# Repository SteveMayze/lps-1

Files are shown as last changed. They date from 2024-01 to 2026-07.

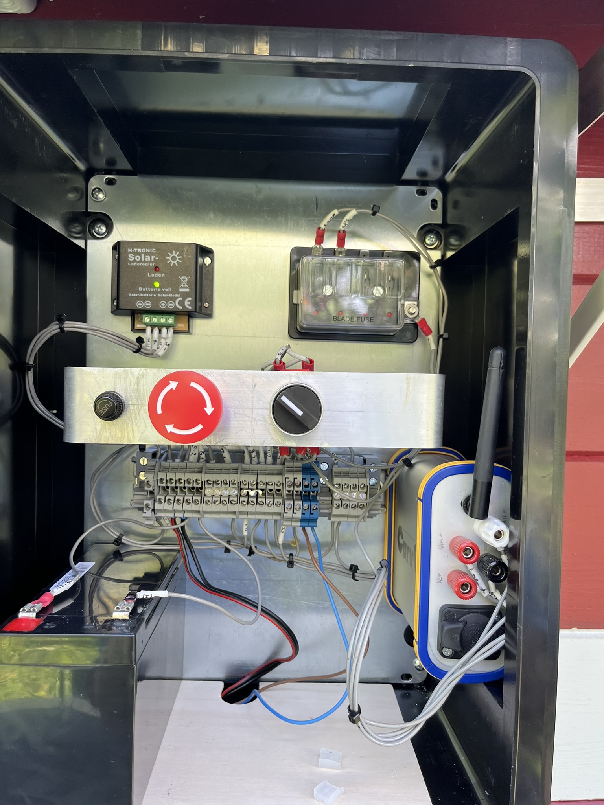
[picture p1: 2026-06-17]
Wiring/LPS-1 Wiring/doc/IMG_8326.JPEG

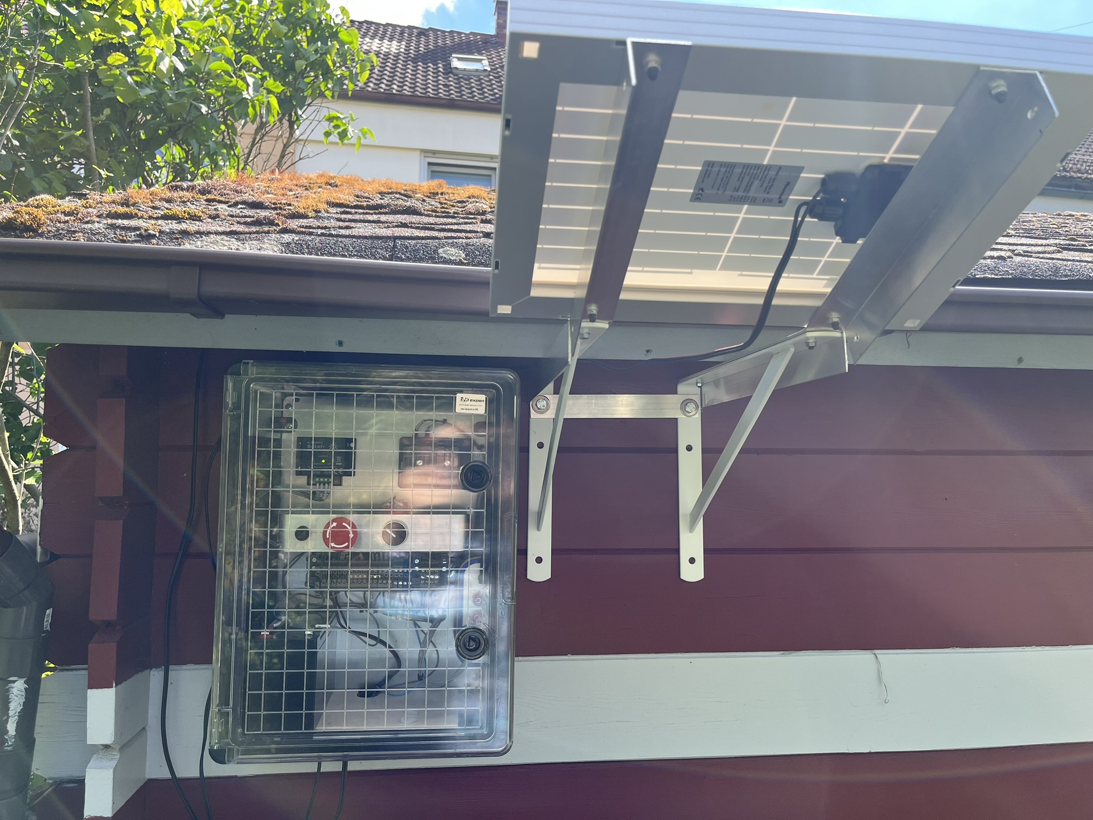
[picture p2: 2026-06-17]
Wiring/LPS-1 Wiring/doc/IMG_8325.JPEG

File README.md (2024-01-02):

# Solar Power Sensor LPS-1

A simple remote sensing node to monitor the voltage and load current for a solar/battery unit.
This unit brings together the prototype projects [Gateway Node](https://github.com/SteveMayze/leawood_gateway),  [Atmega1608 Development board](https://github.com/SteveMayze/atmega1608_dev) and [Sensor node firmware (Atmega1608 and INA219)](https://github.com/SteveMayze/PowerSensor-Atmega1608) to create a unified PCB that can be deployed to the field to make a connection to the gateway project in order to transfer the sensor data to the internet.

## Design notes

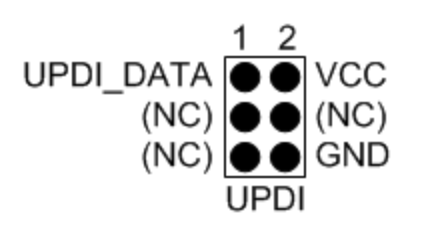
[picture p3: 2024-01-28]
doc/UPDI_PINOUT.png

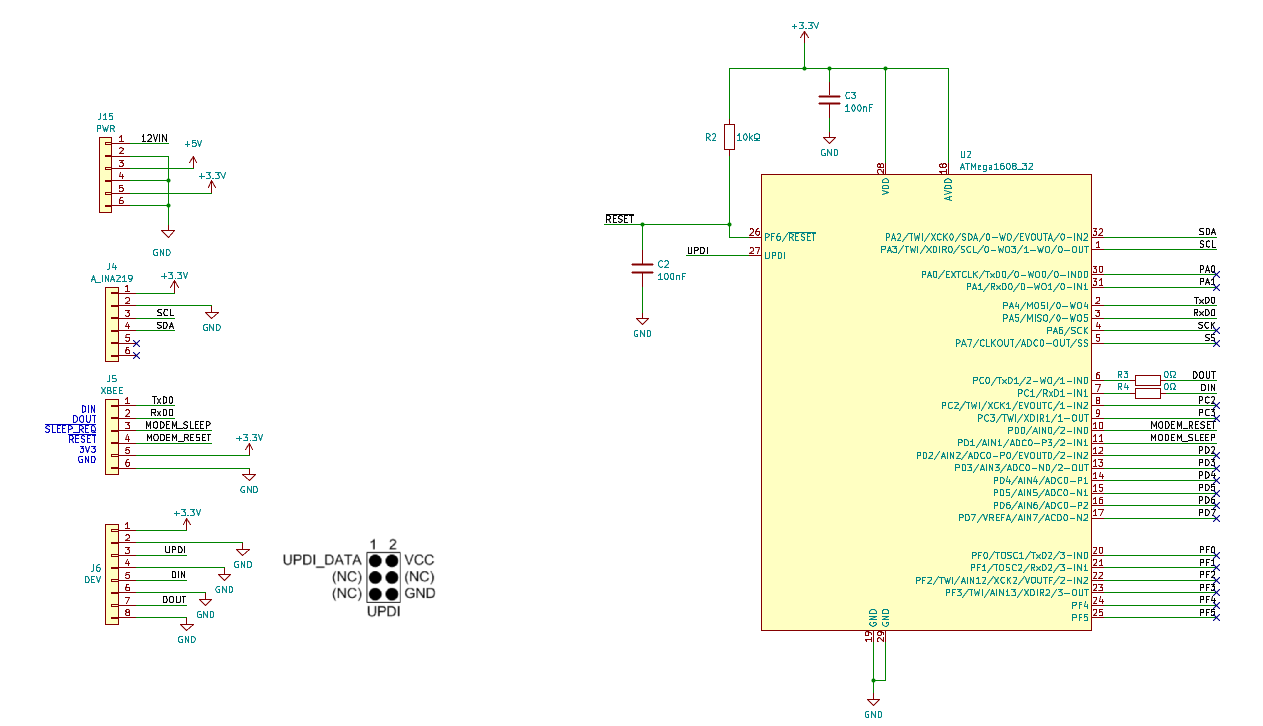
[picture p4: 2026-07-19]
doc/Schematic.png

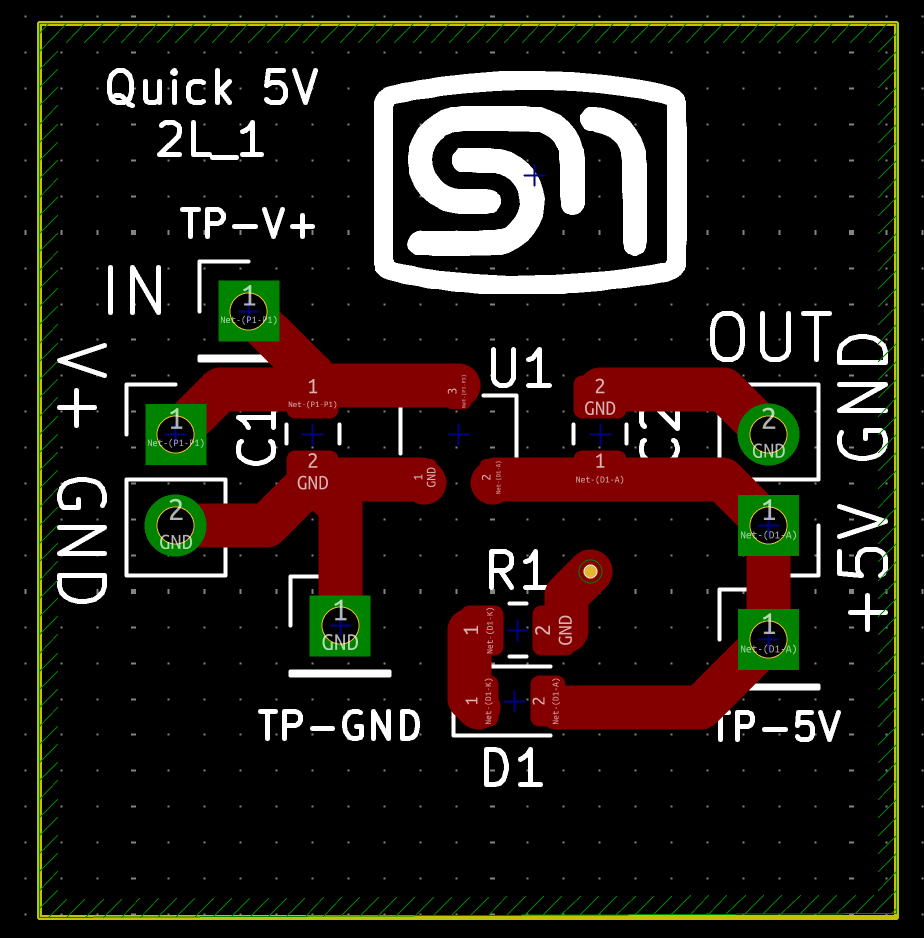
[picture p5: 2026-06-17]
doc/KiCad-PCB-Sample.png

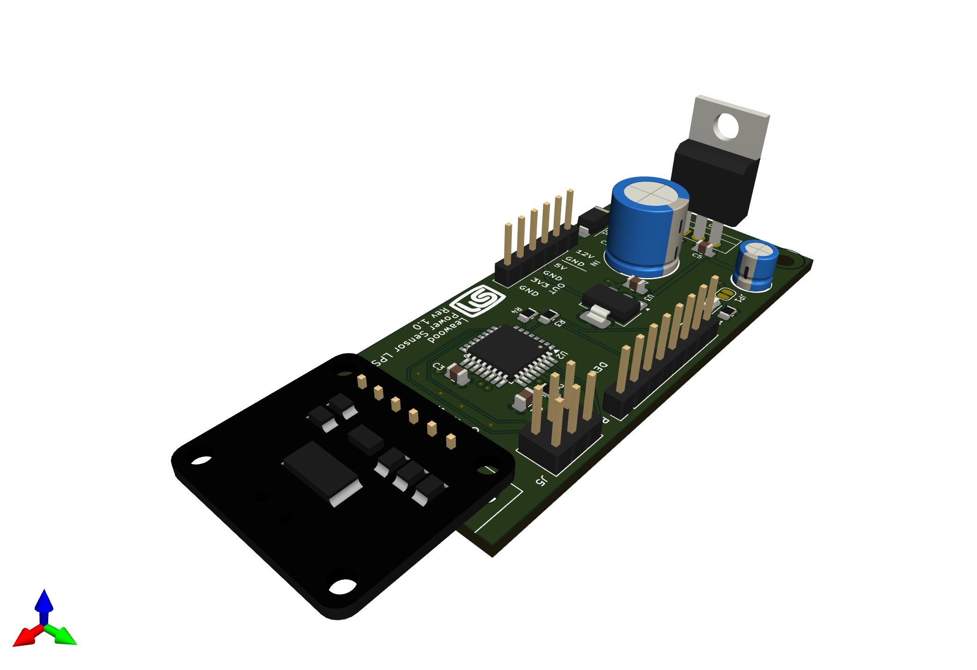
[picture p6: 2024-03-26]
doc/lps-1.jpg

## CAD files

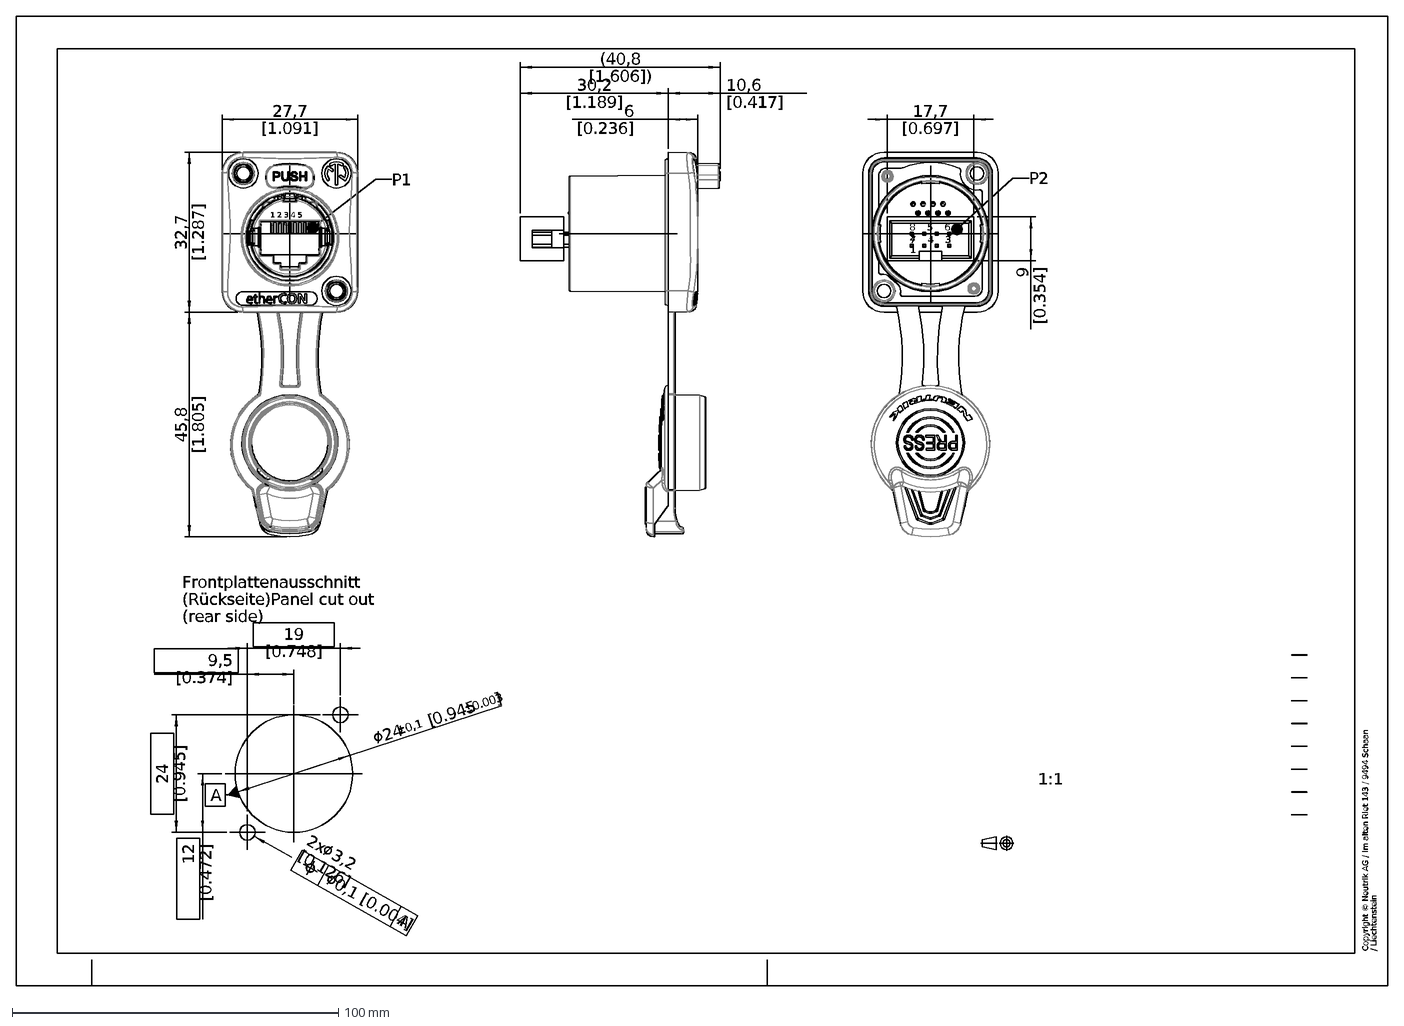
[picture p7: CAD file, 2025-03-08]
doc/Drawing NE8FDIS-TOP.dxf
Copyright © Neutrik AG / Im alten Riet 143 / 9494 Schaan / Liechtenstein
27,7 [1.091]
32,7 [1.287]
45,8 [1.805]
30,2 [1.189]
(40,8 [1.606])
10,6 [0.417]
6 [0.236]
17,7 [0.697]
9 [0.354]
24
0,1
[
0.945
0.003
]
2x 3,2 [0.126]
19 [0.748]
24 [0.945]
9,5 [0.374]
12 [0.472]
0,1 [0.004]
A
7 4 3 1
8 5 6 2
1 2 3 4 5 6 7 8
Frontplattenausschnitt (Rückseite) Panel cut out (rear side)
P1
P2
1:1

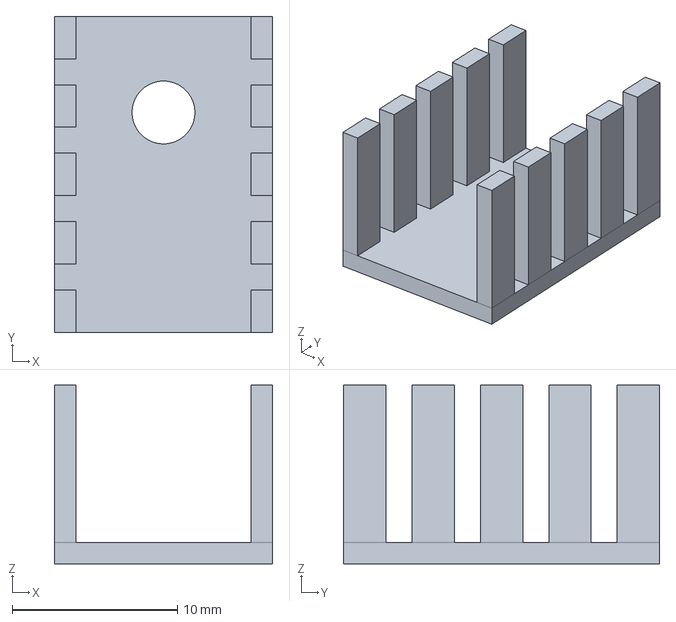
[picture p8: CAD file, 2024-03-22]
models/Wakefield-E274.step
13.2 x 19.1 x 10.8 mm

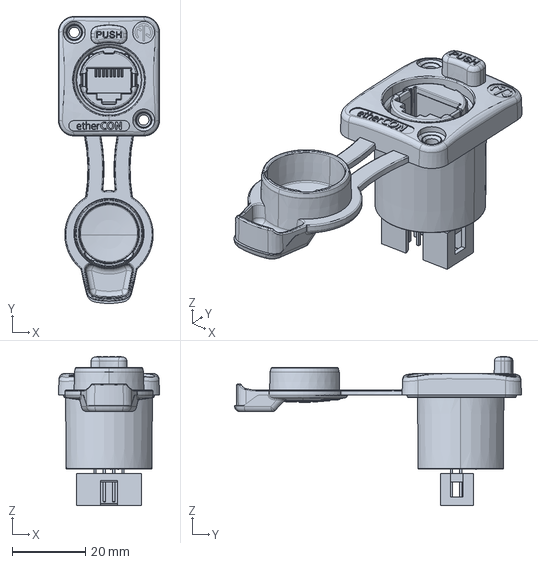
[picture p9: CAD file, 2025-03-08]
doc/3D File NE8FDIS-TOP.stp
27.7 x 78.6 x 40.8 mm

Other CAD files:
doc/ConnectorPanel.FCStd
models/Wakefield-E274-Body.step
models/Wakefield-E274.FCStd

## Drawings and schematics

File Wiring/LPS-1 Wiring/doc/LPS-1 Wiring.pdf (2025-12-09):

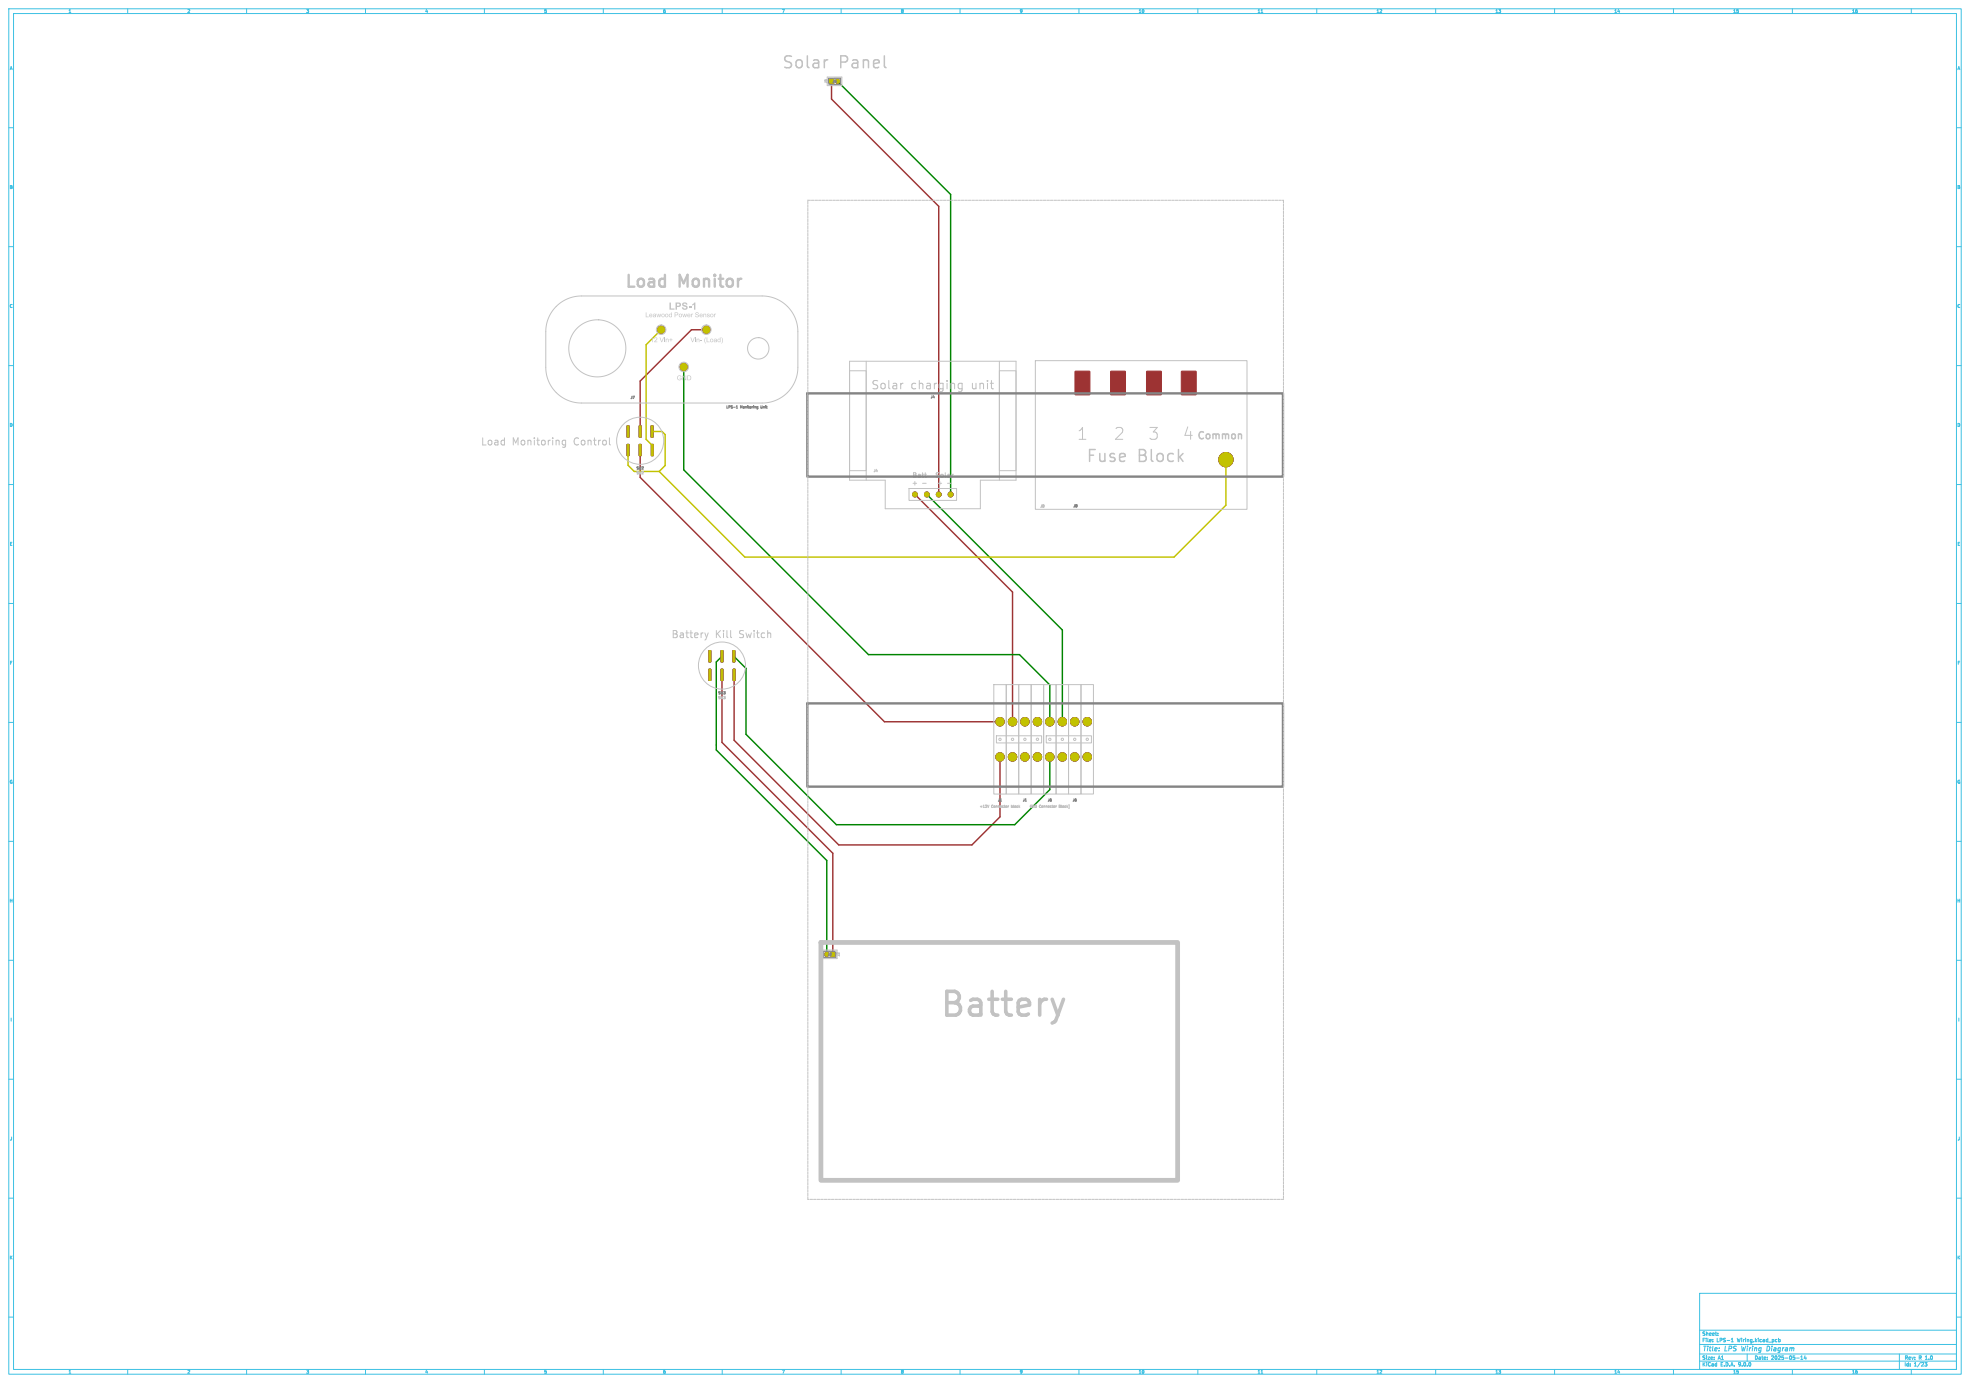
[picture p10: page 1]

J4 Solar charging | unit

Id: 1/23 Title: LPS Wiring Diagram

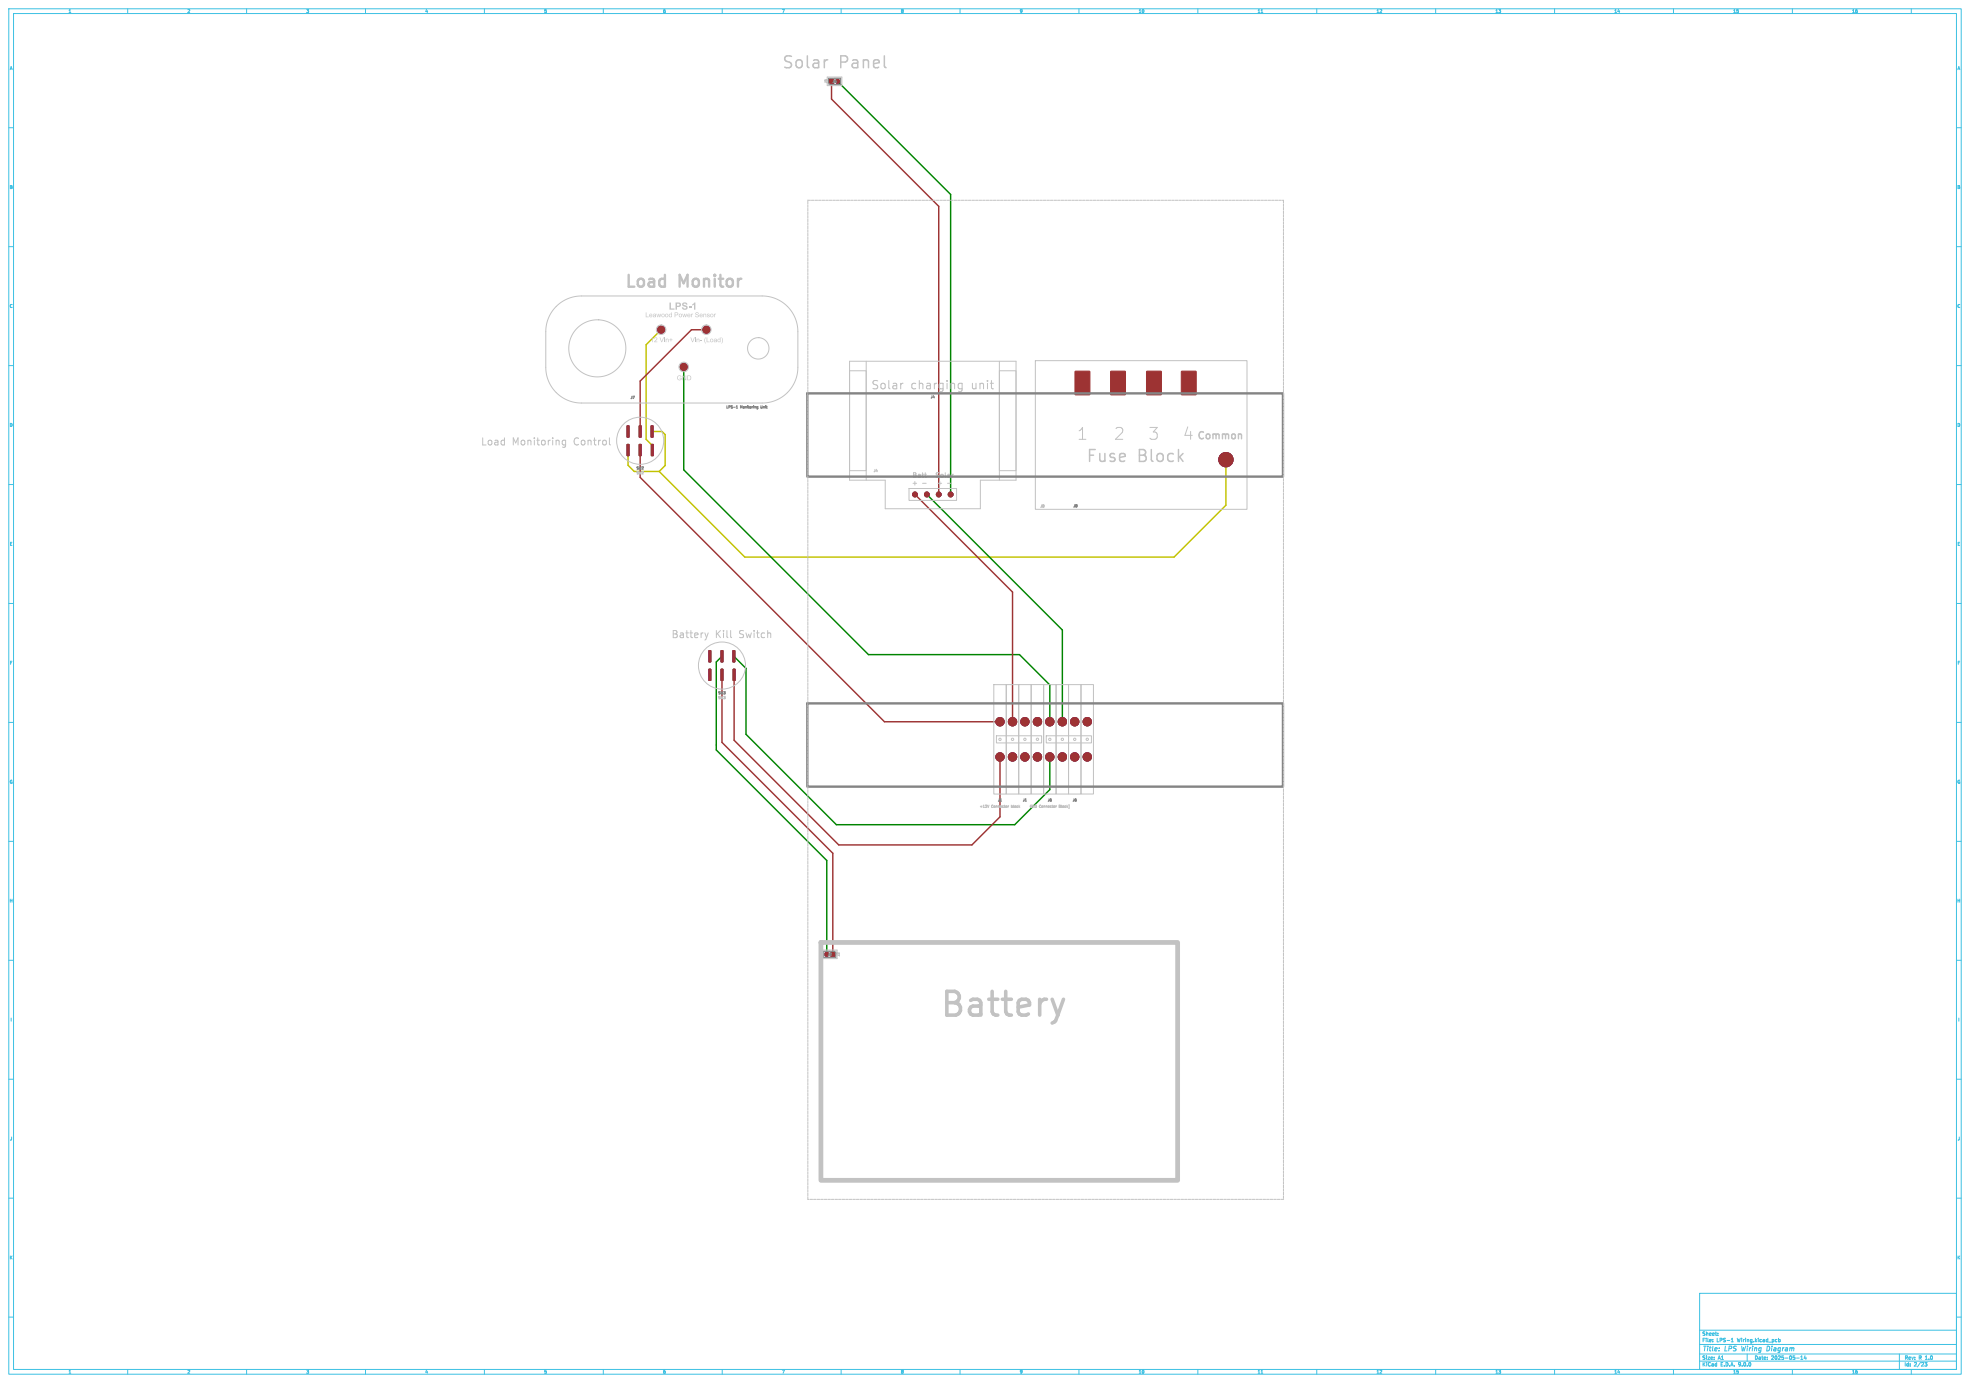
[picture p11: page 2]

J4 Solar charging | unit

Id: 2/23 Title: LPS Wiring Diagram

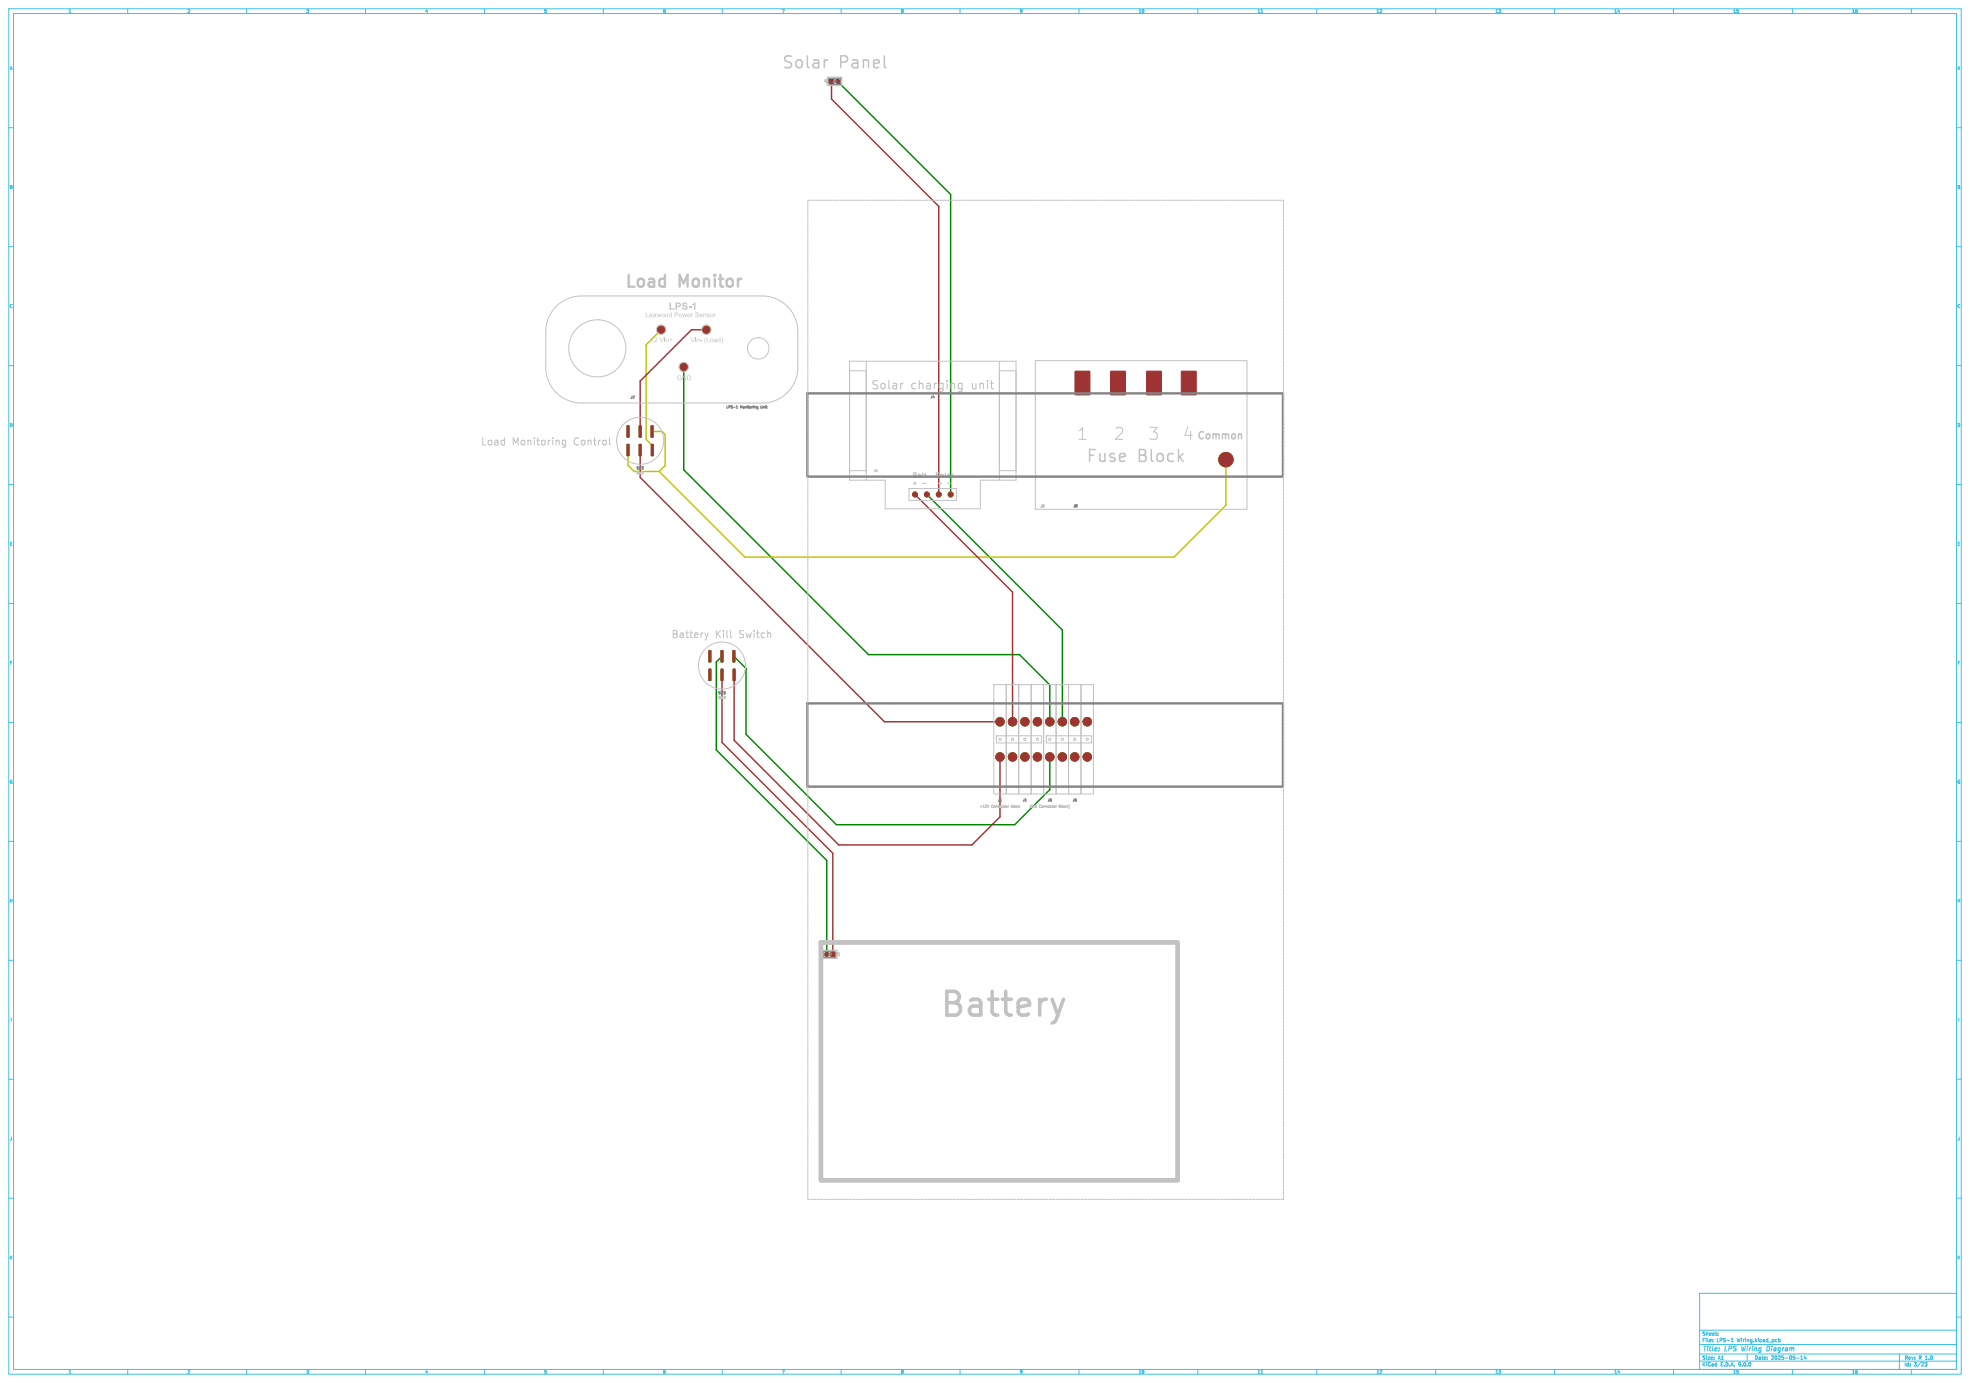
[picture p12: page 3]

J4 Solar charging | unit

Id: 3/23 Title: LPS Wiring Diagram

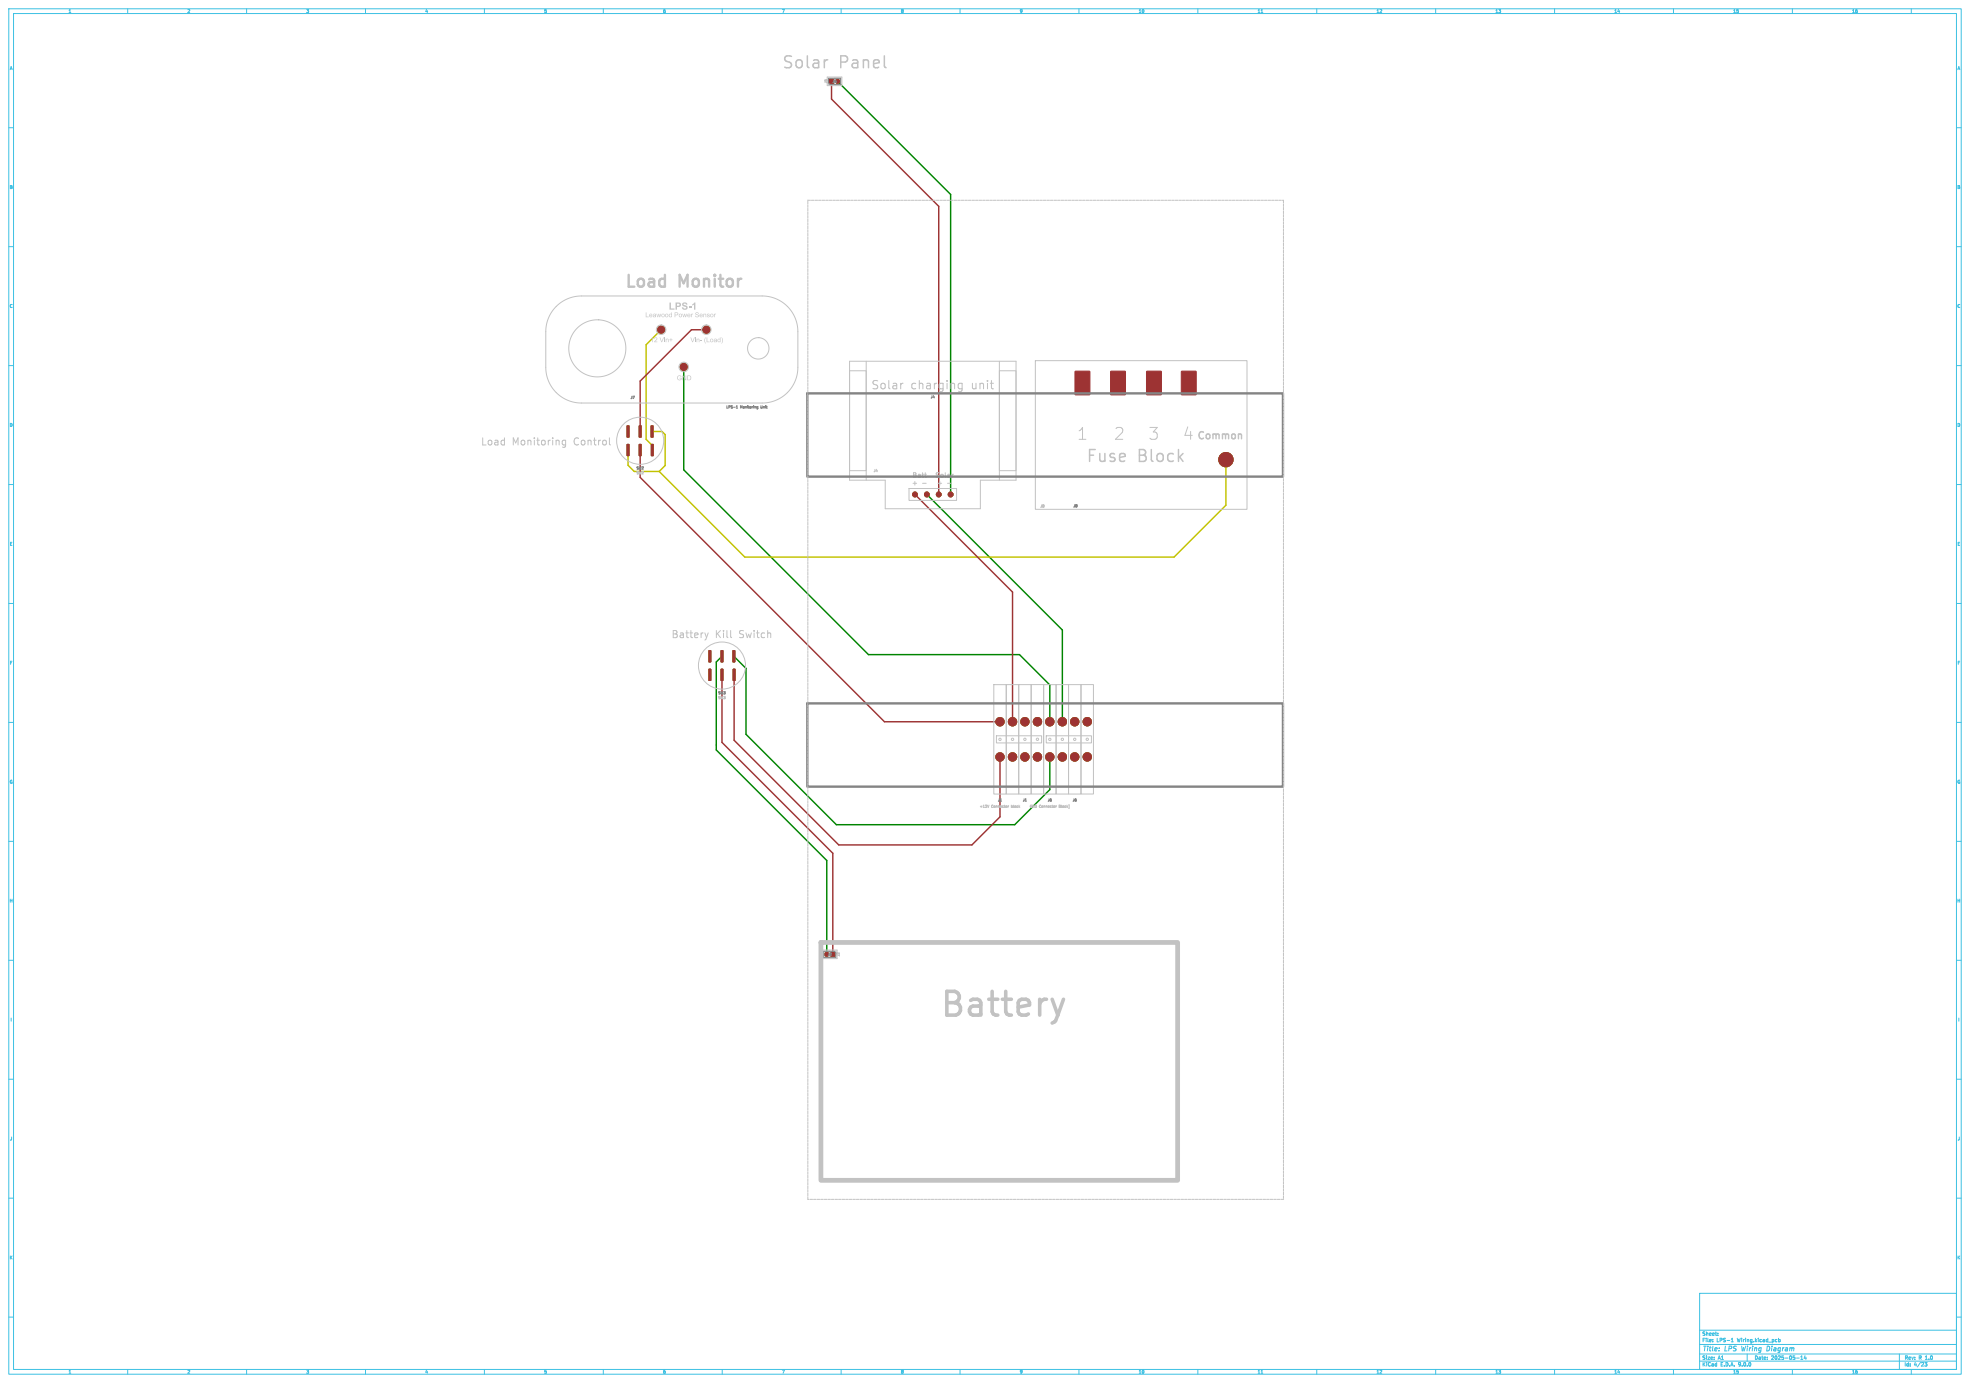
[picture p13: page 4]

J4 Solar charging | unit

Id: 4/23 Title: LPS Wiring Diagram

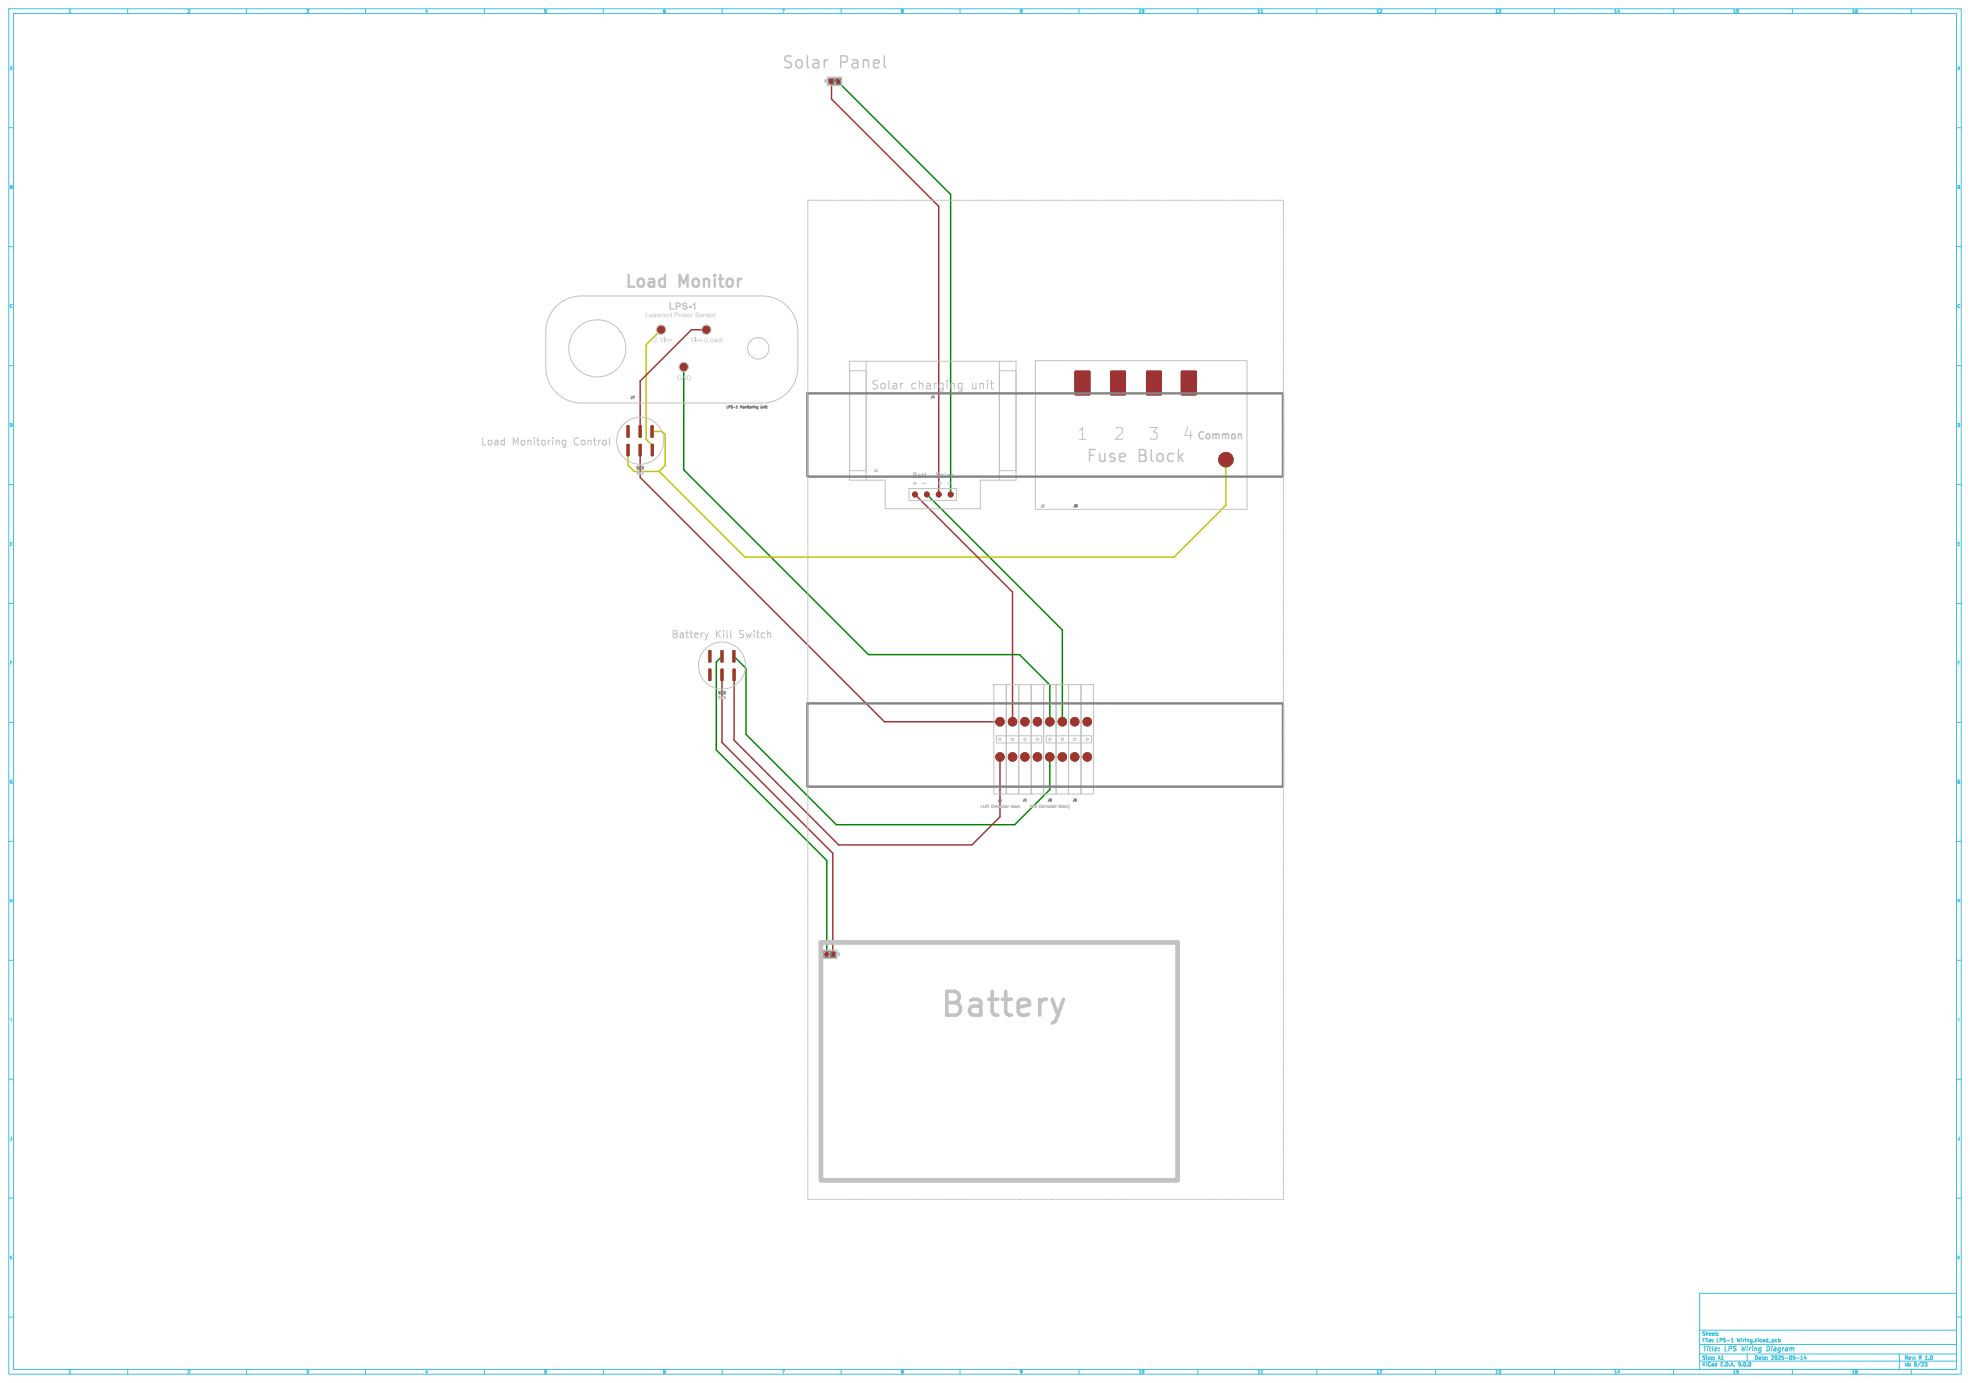
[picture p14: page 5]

J4 Solar charging | unit

Id: 5/23 Title: LPS Wiring Diagram

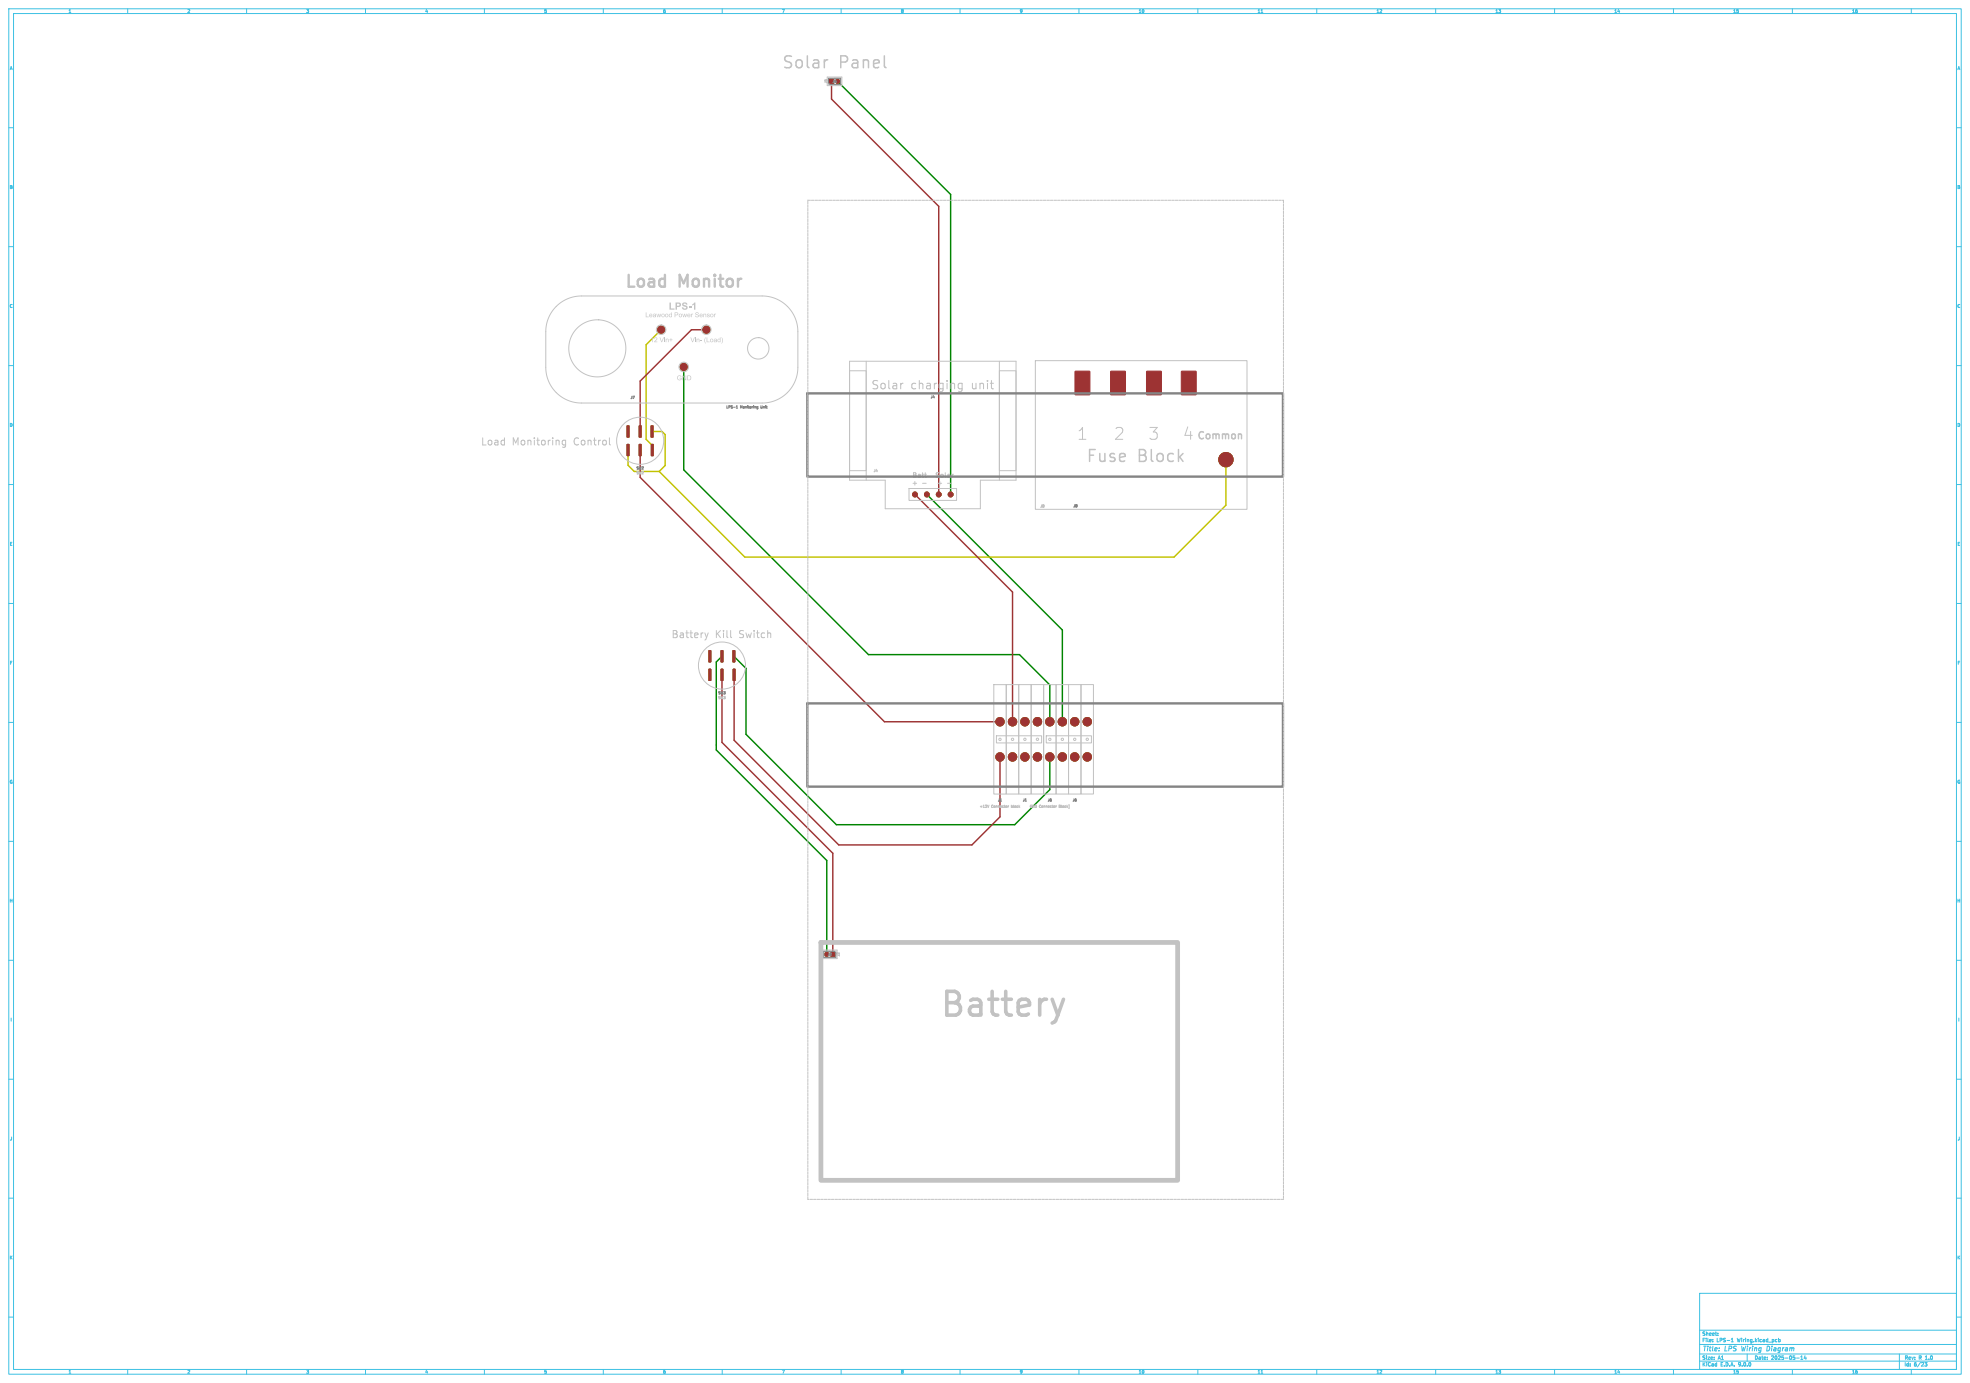
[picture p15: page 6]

J4 Solar charging | unit

Id: 6/23 Title: LPS Wiring Diagram

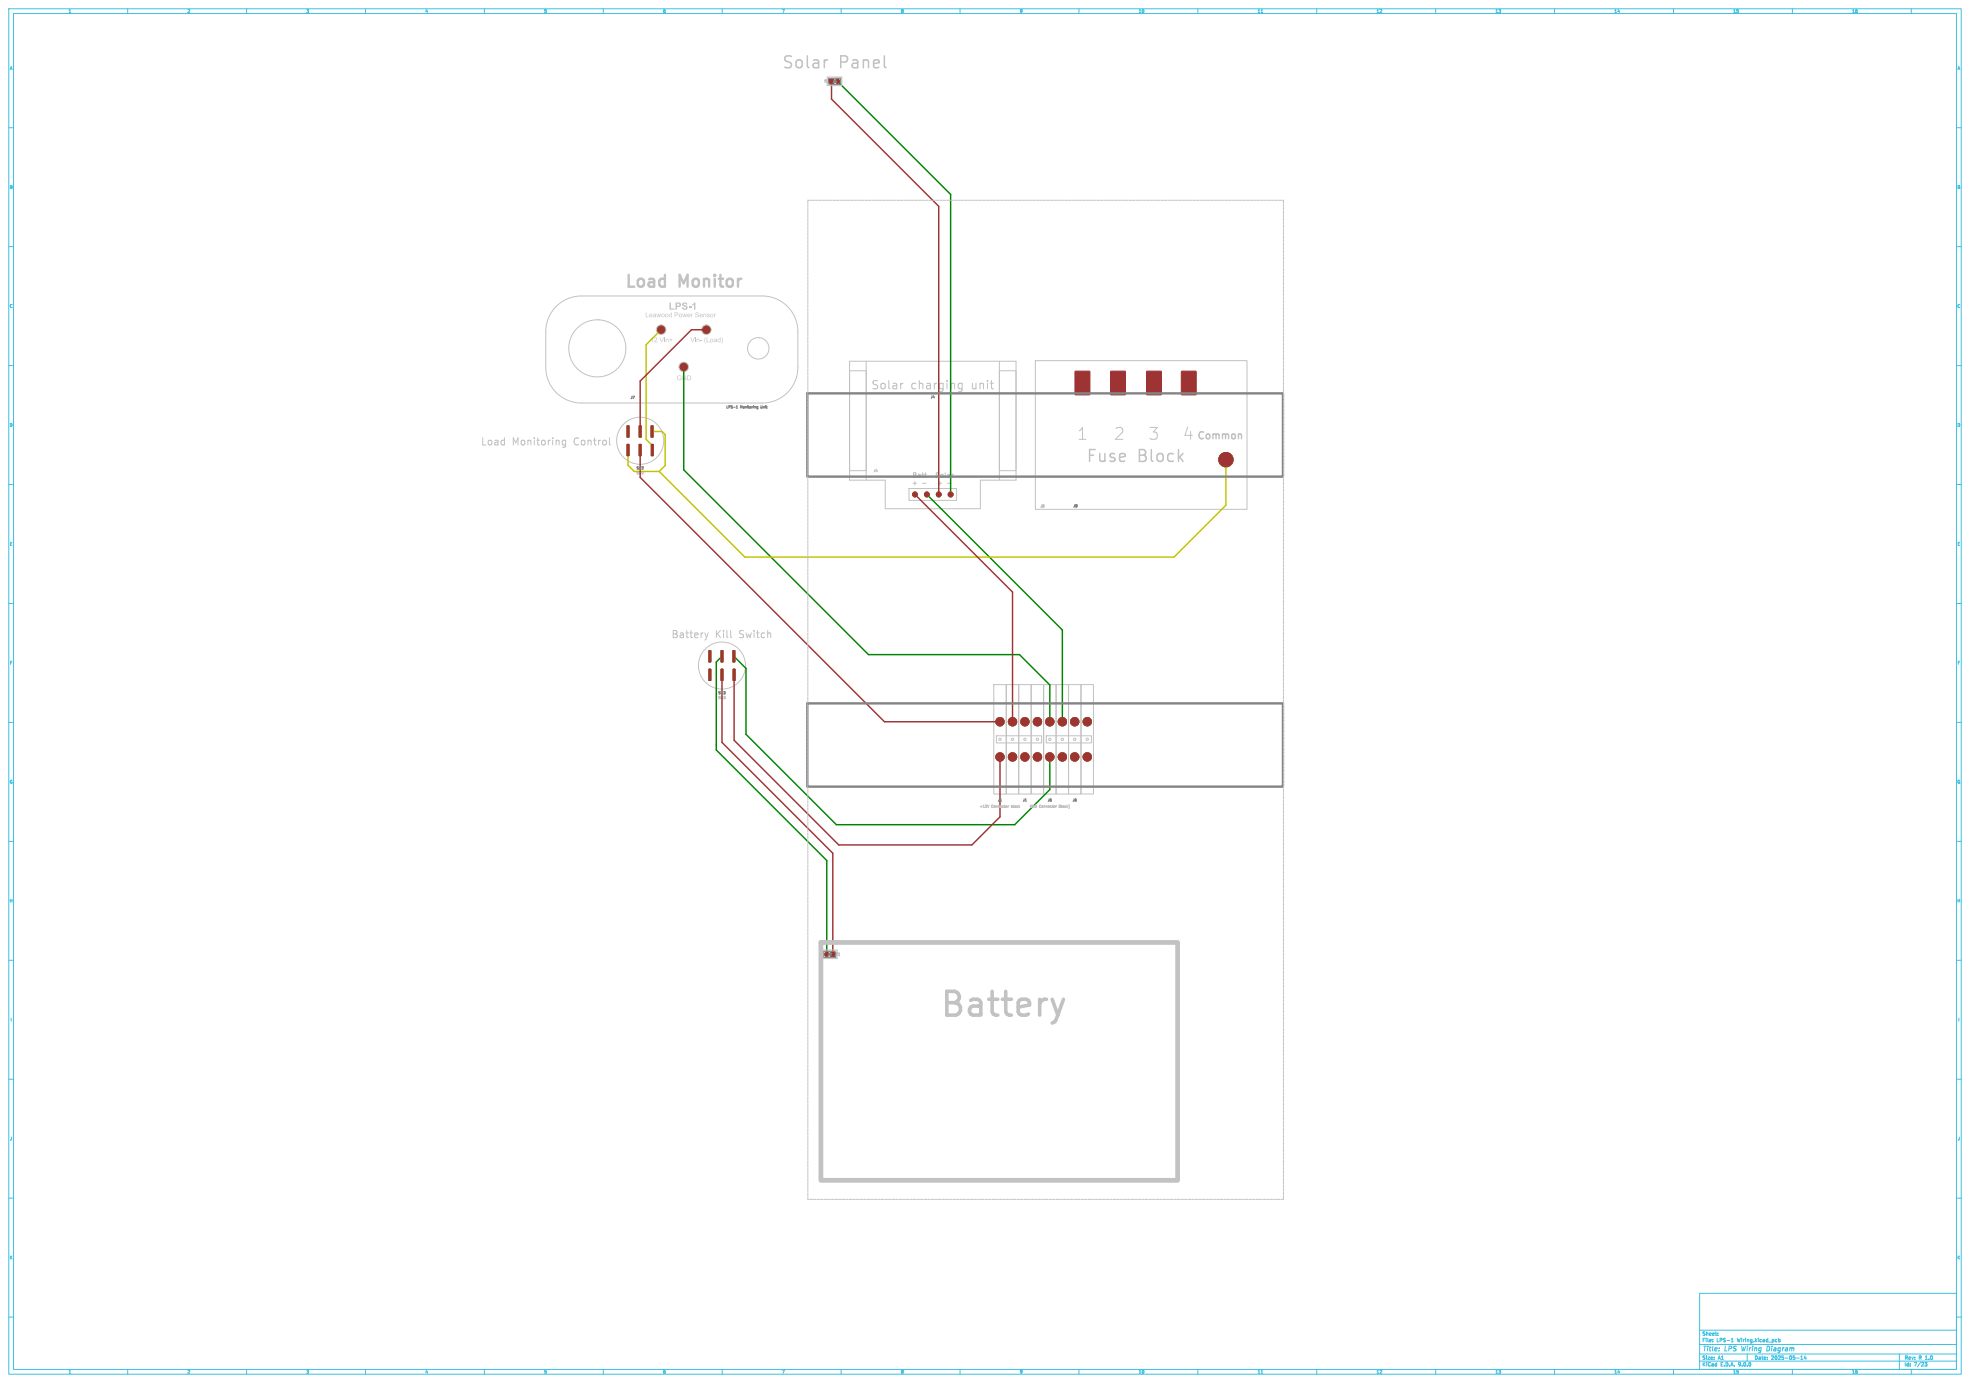
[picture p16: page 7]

J4 Solar charging | unit

Id: 7/23 Title: LPS Wiring Diagram

J4 Solar charging | unit

Id: 8/23 Title: LPS Wiring Diagram

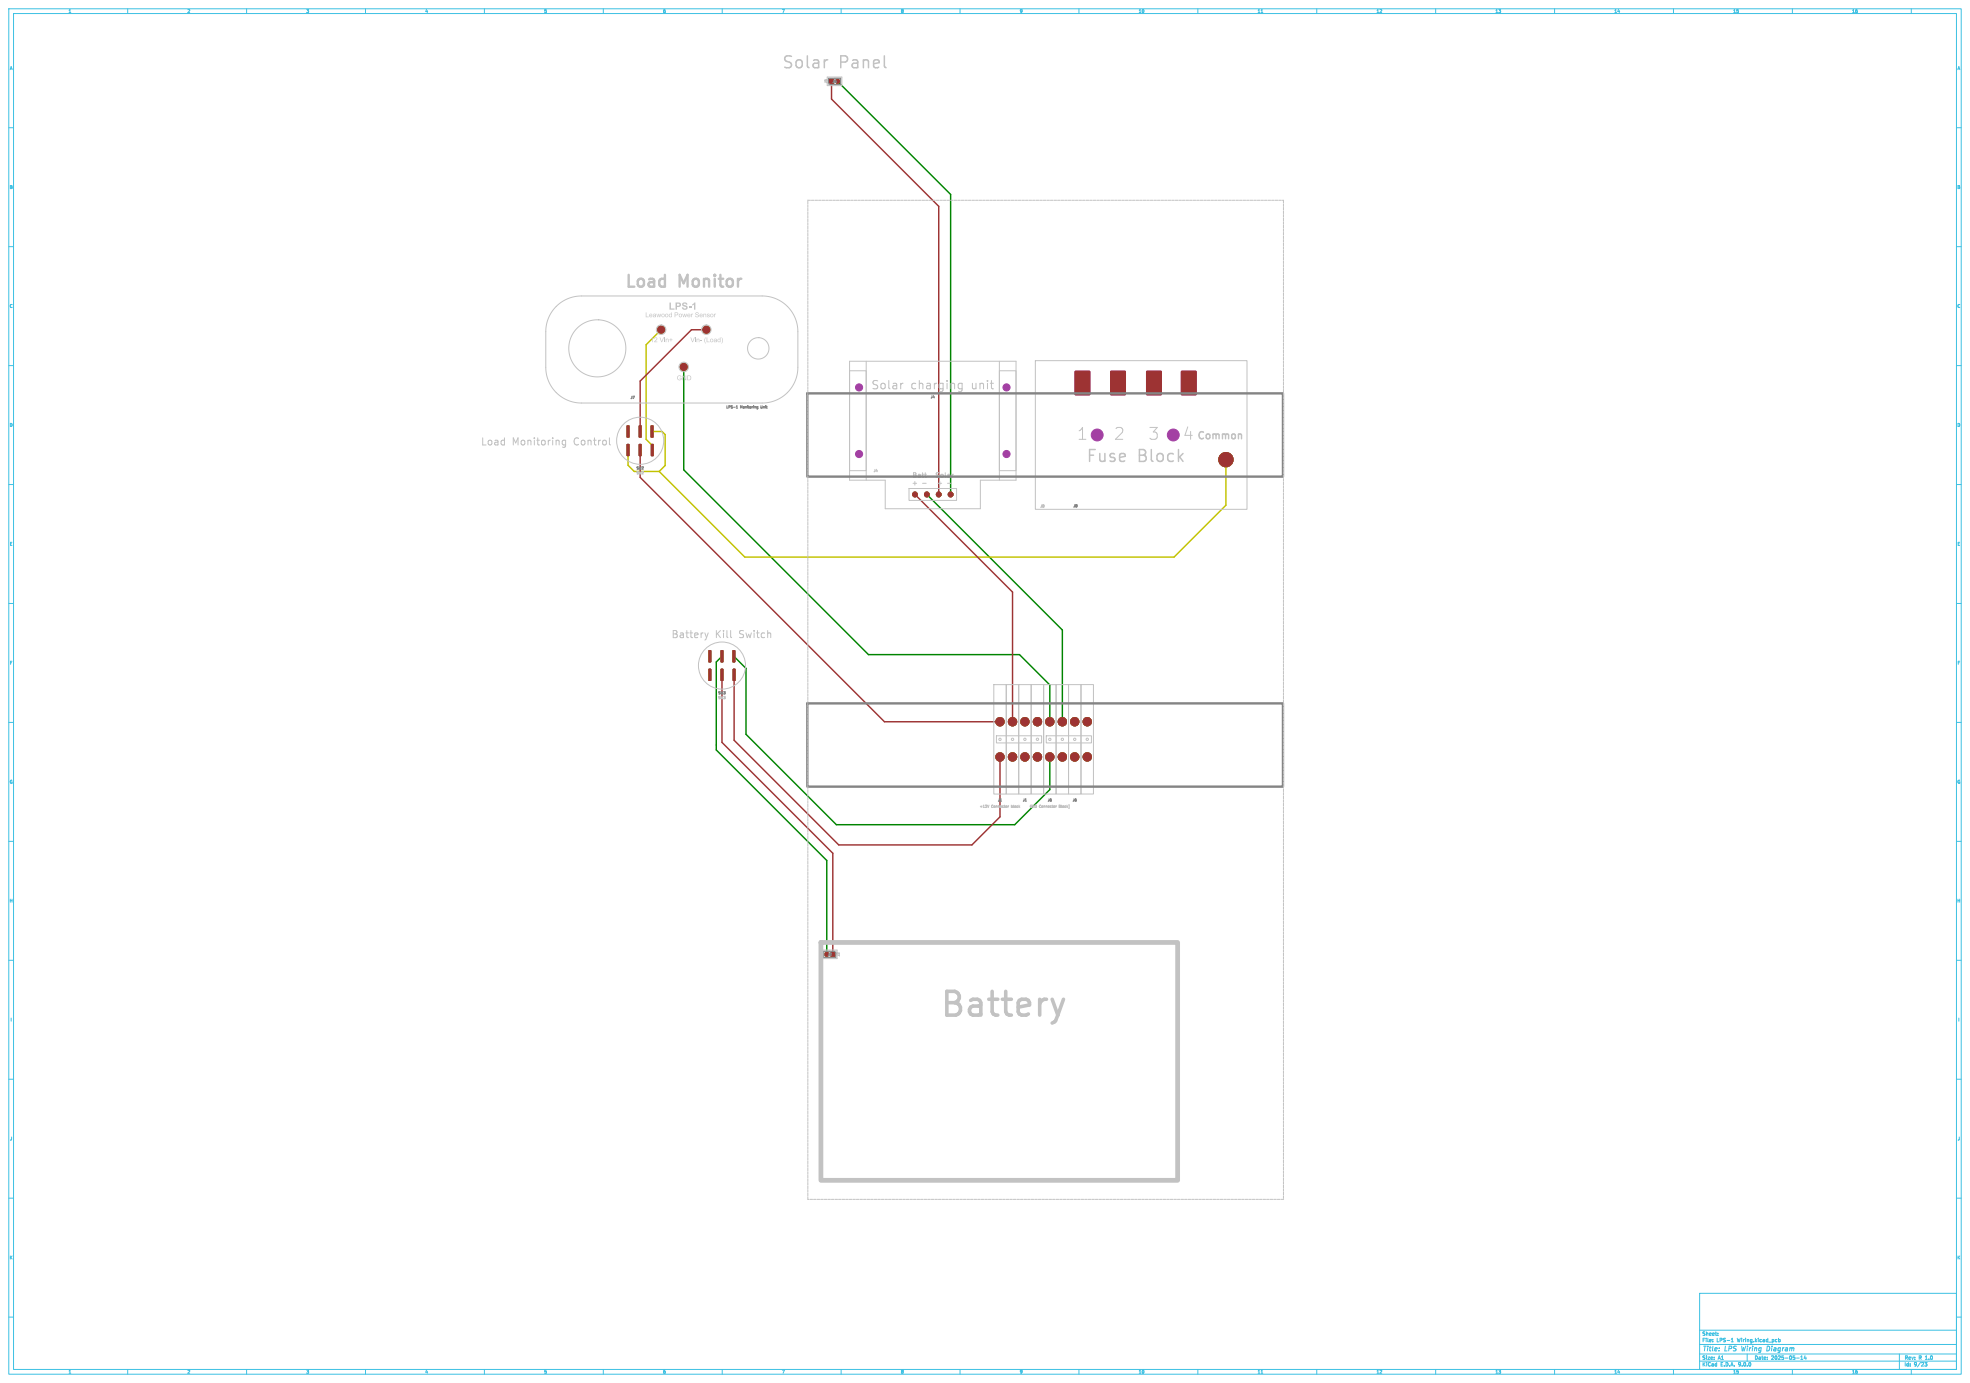
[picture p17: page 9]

J4 Solar charging | unit

Id: 9/23 Title: LPS Wiring Diagram

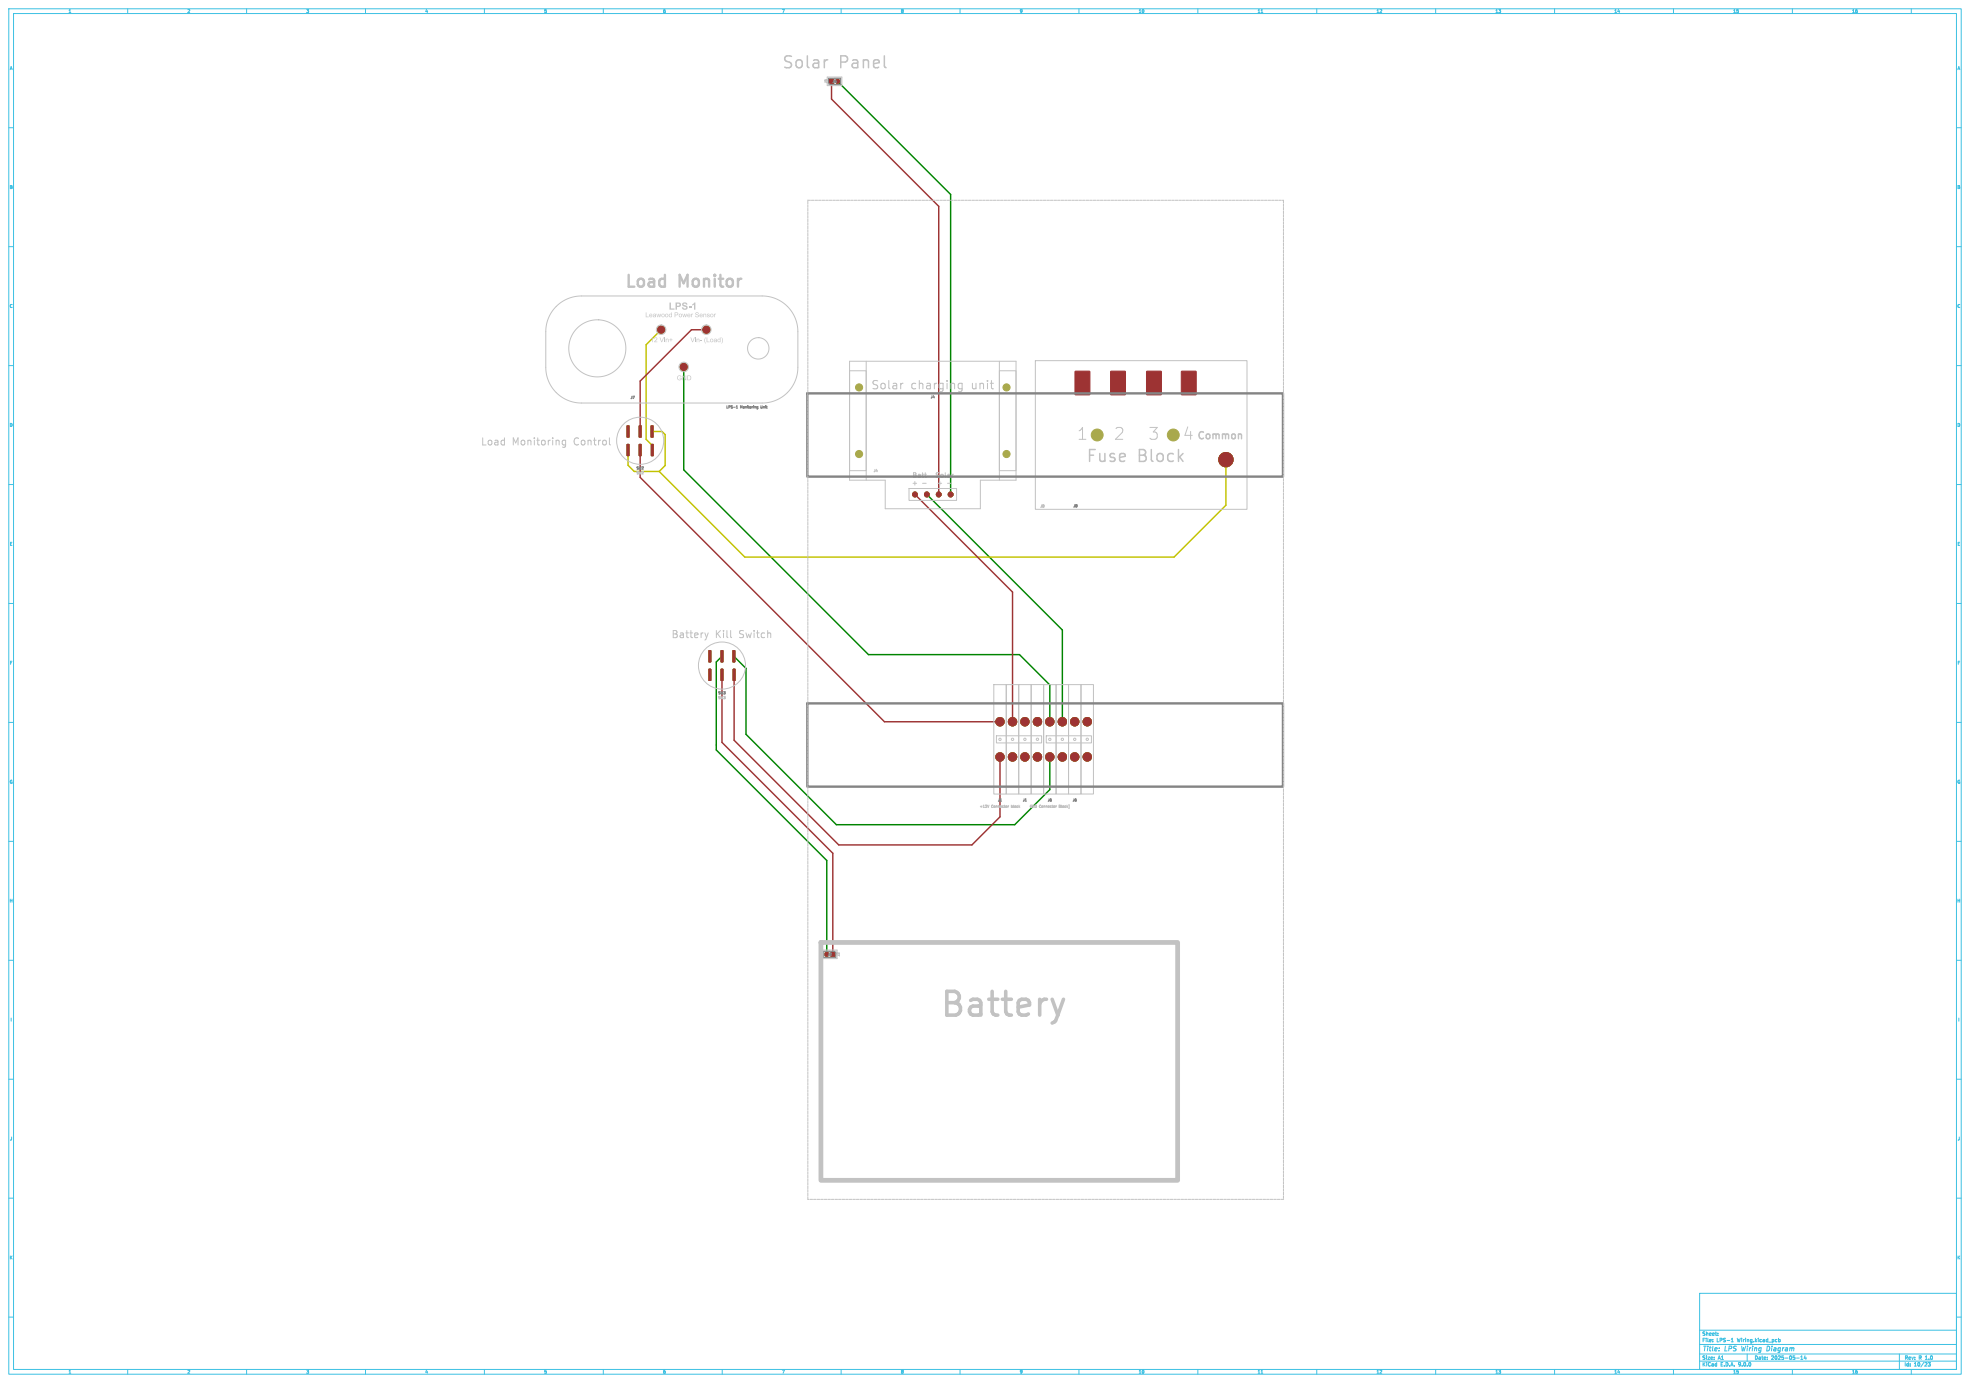
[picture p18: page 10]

J4 Solar charging | unit

Id: 10/23 Title: LPS Wiring Diagram

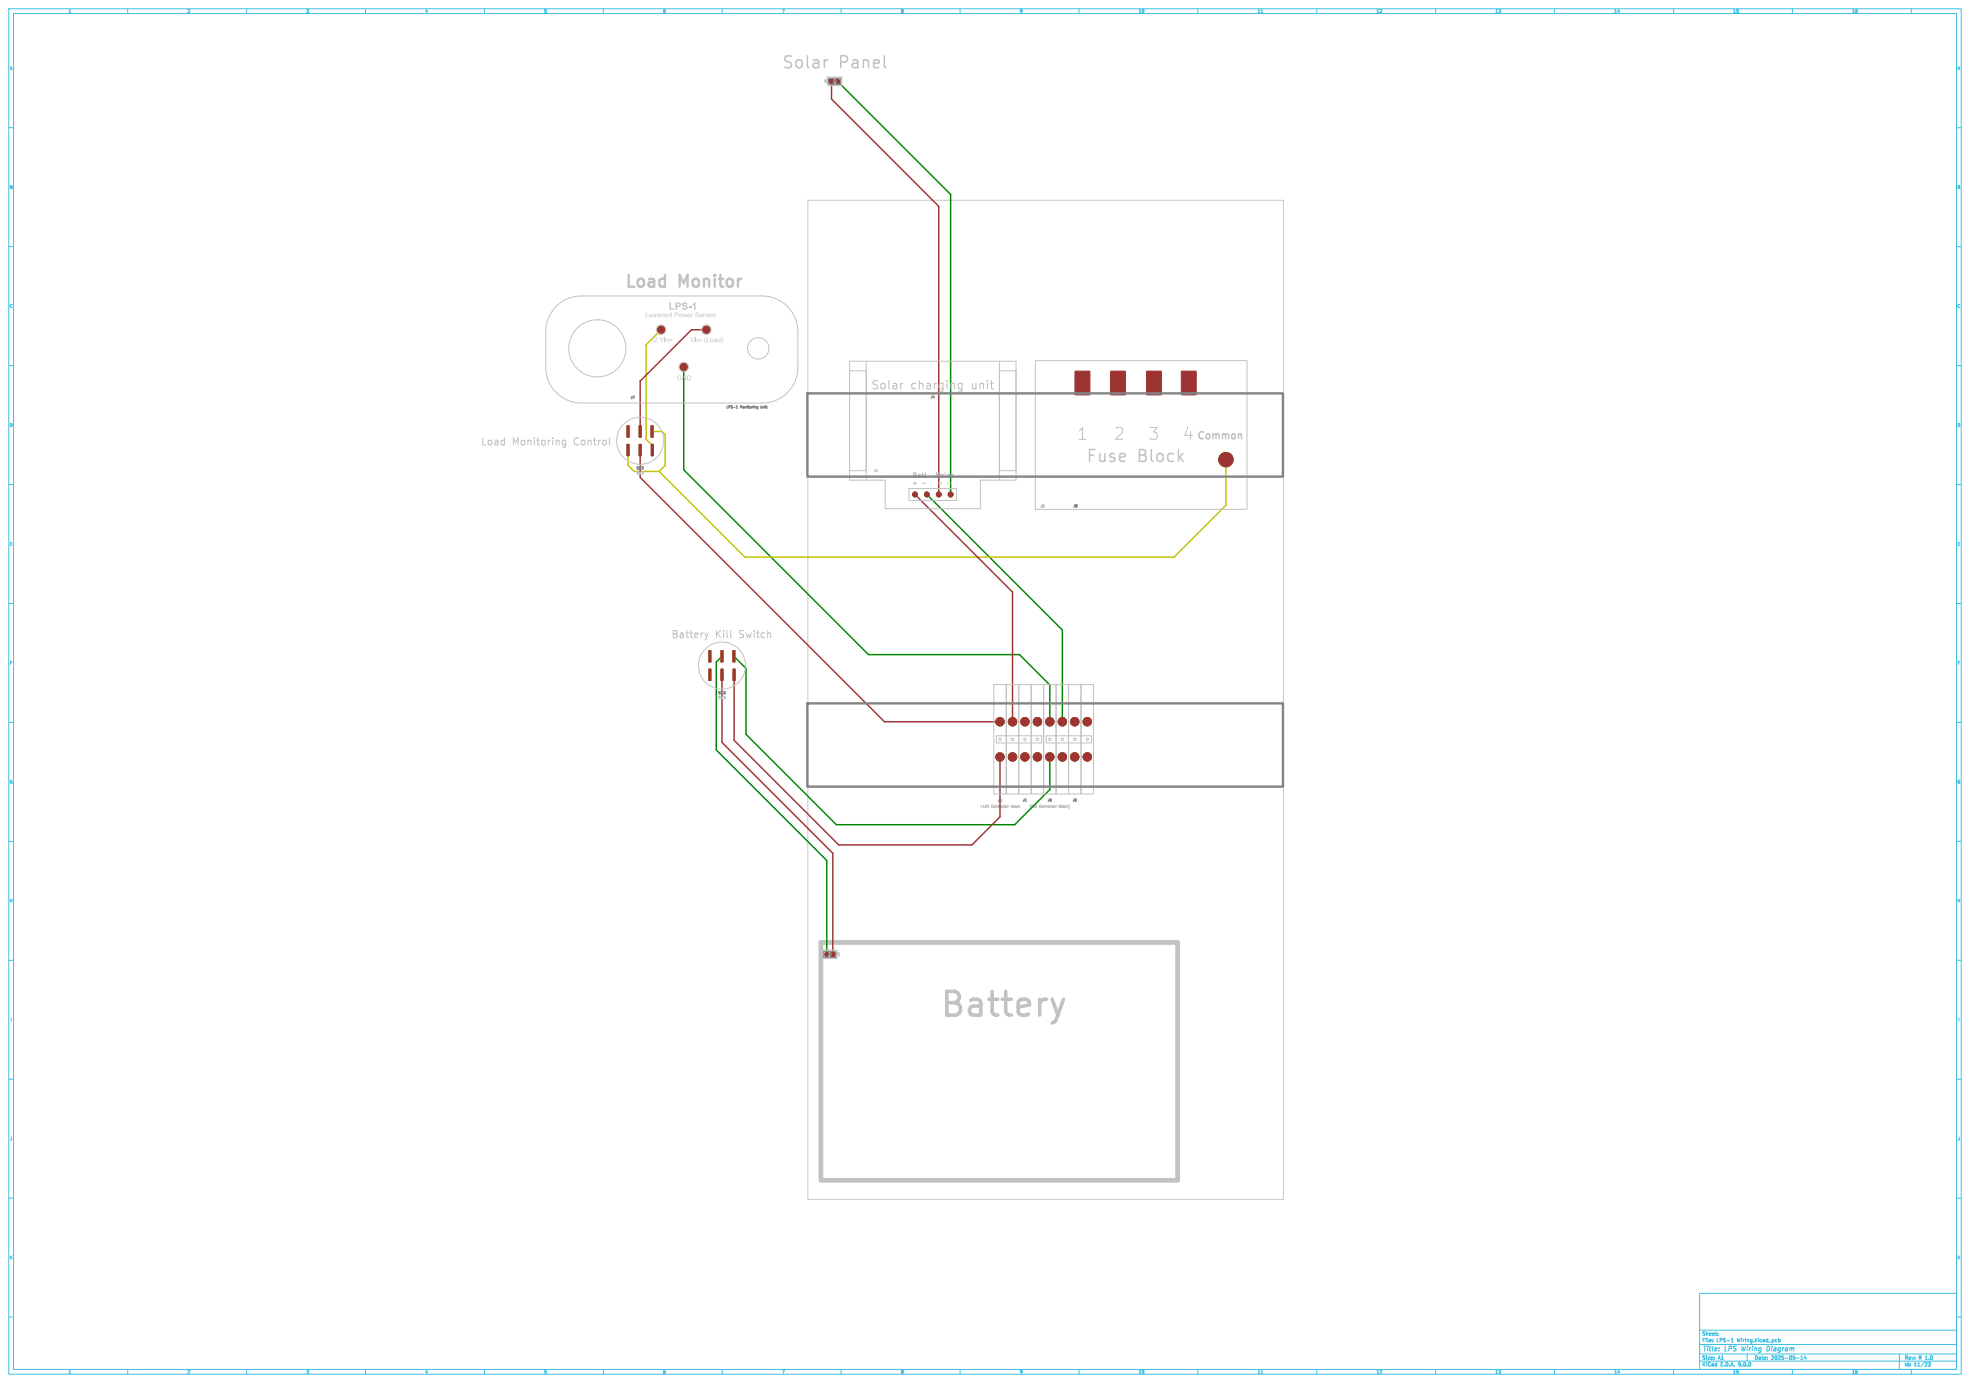
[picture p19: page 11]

J4 Solar charging | unit

Id: 11/23 Title: LPS Wiring Diagram

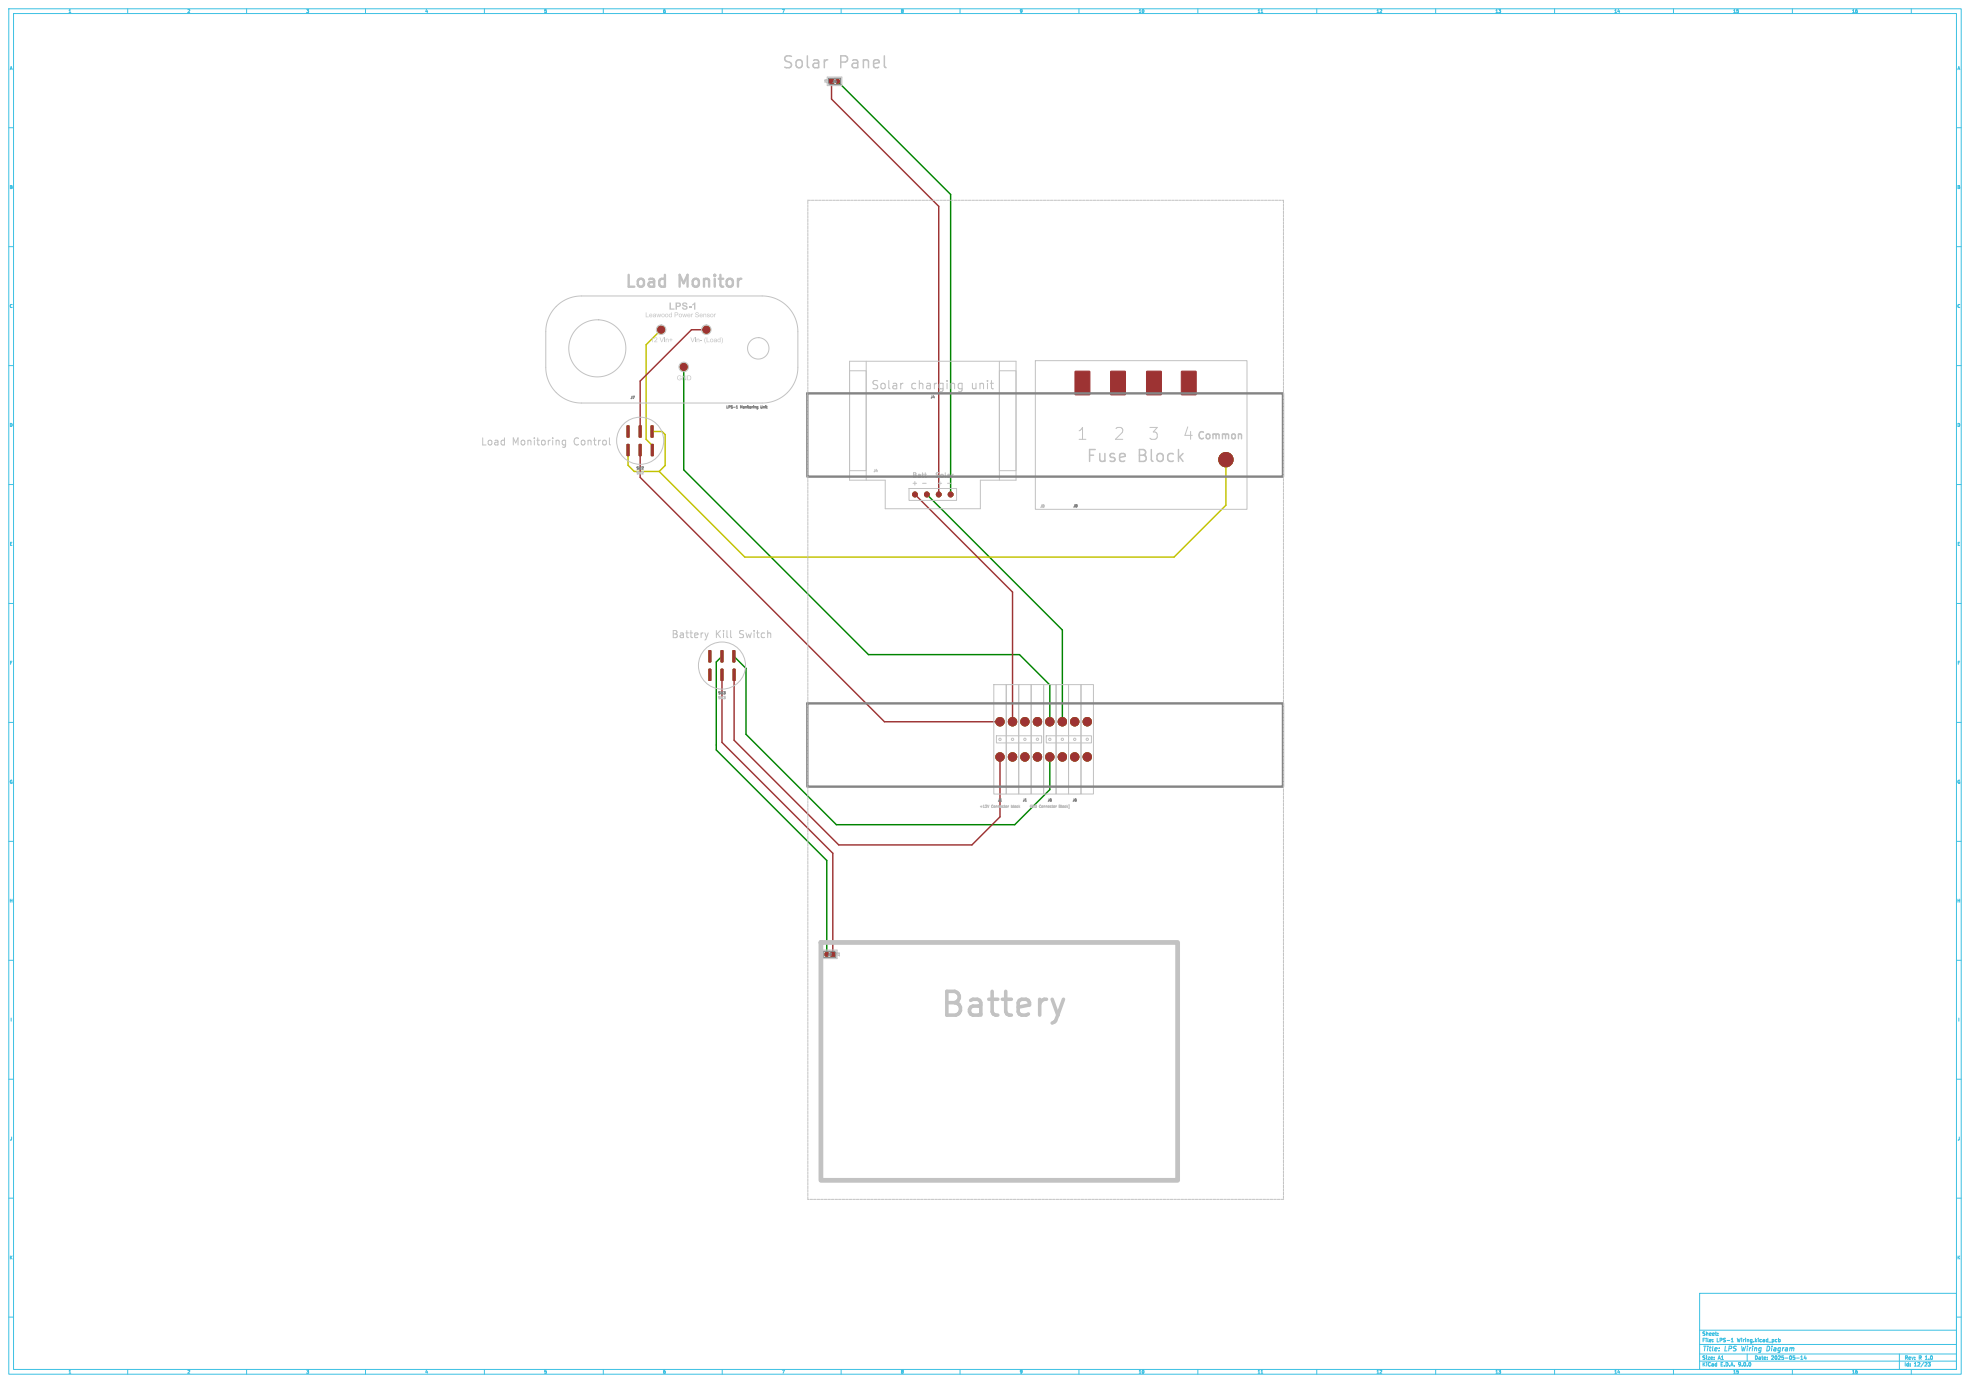
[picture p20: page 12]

J4 Solar charging | unit

Id: 12/23 Title: LPS Wiring Diagram

J4 Solar charging | unit

Id: 13/23 Title: LPS Wiring Diagram

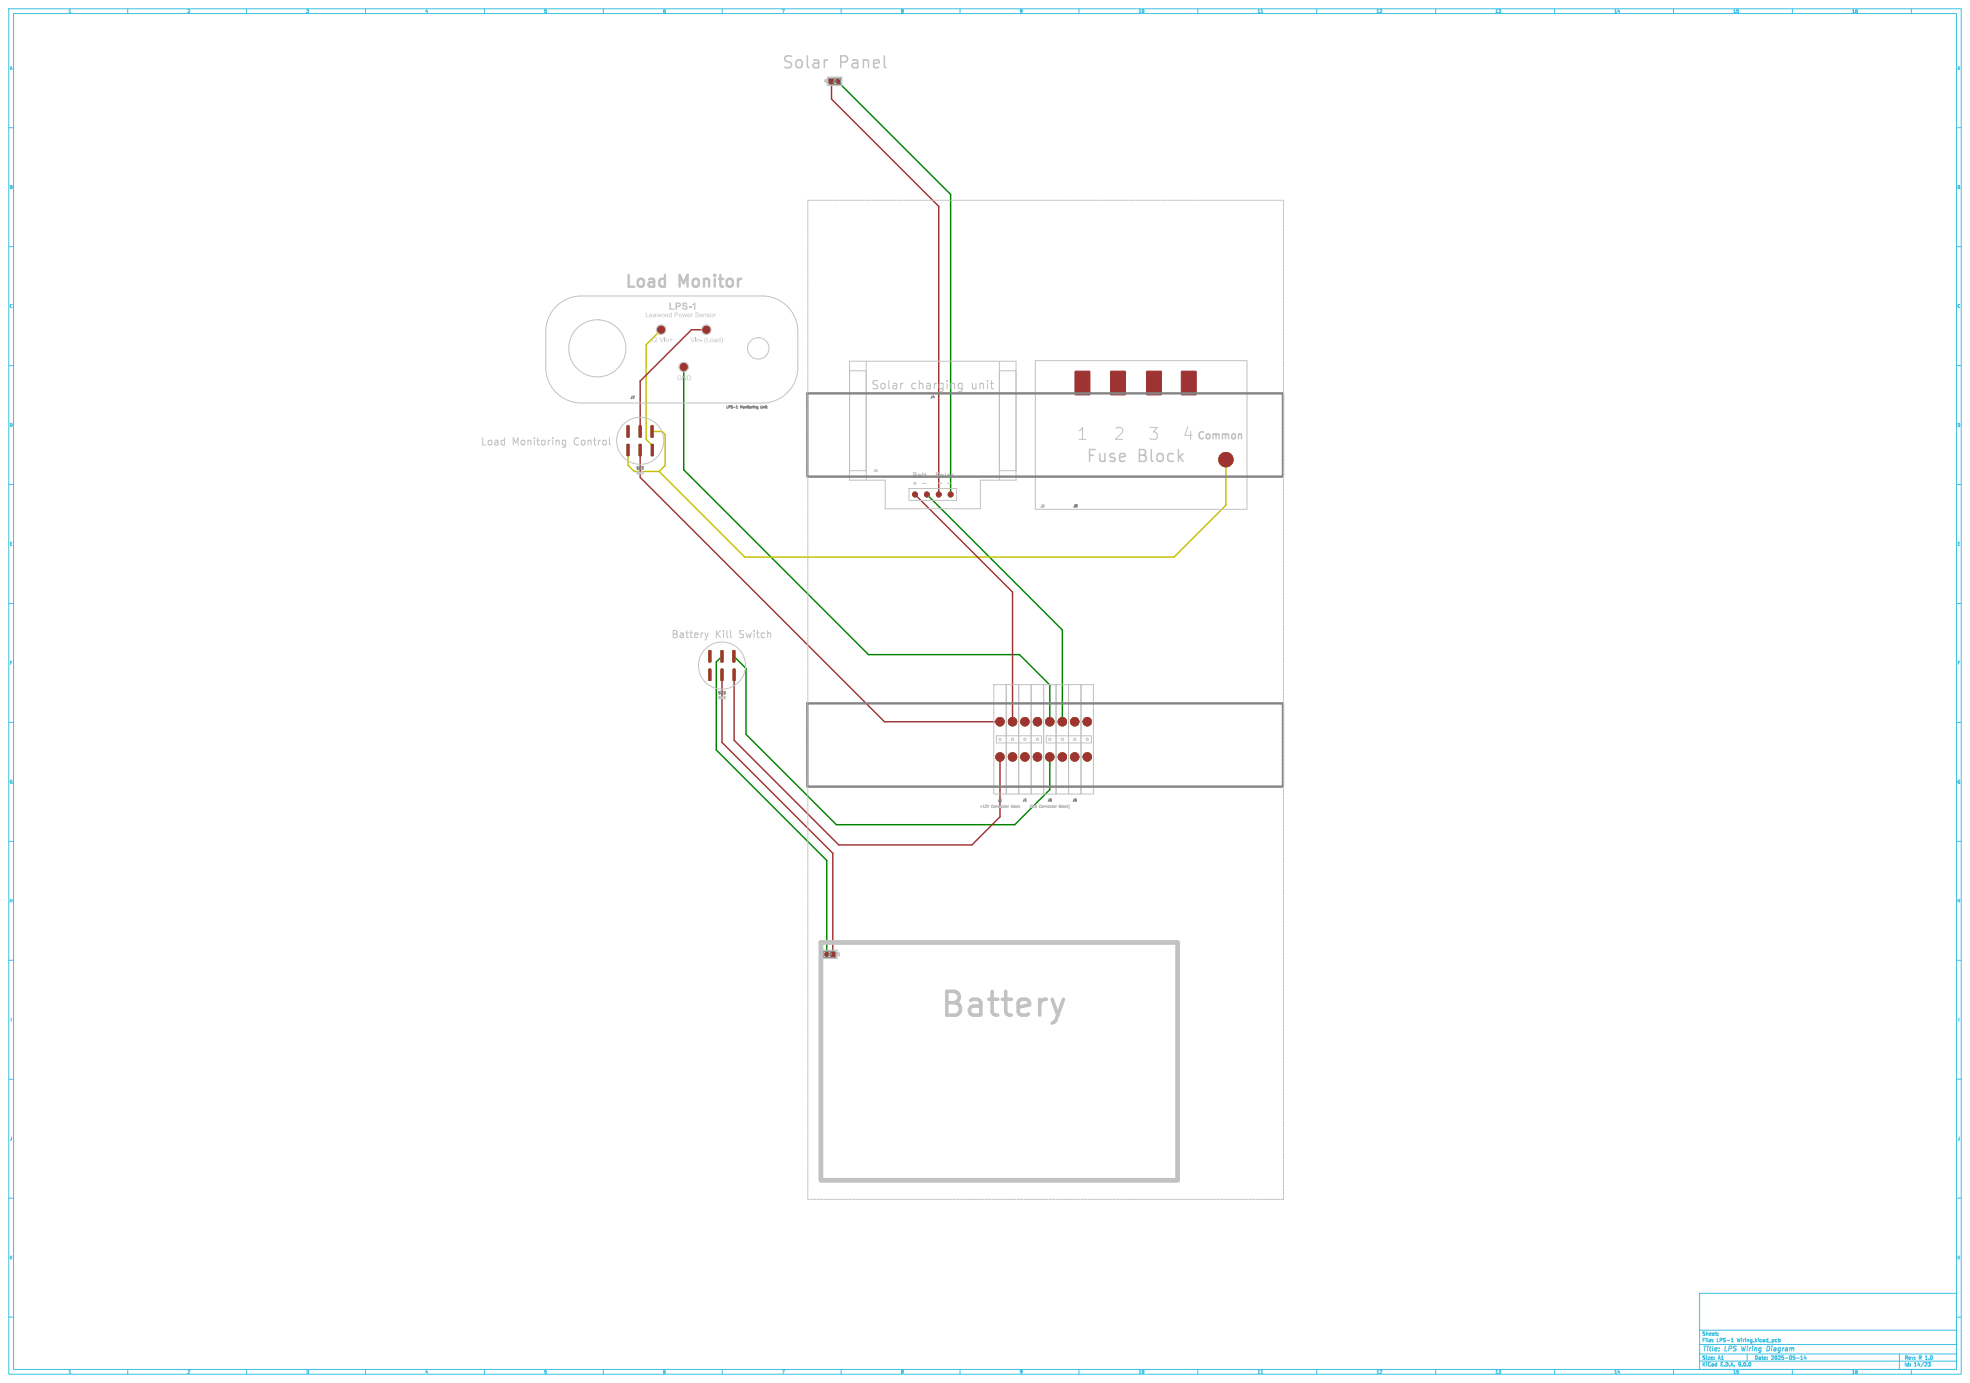
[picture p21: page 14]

J4 Solar charging | unit

Id: 14/23 Title: LPS Wiring Diagram

J4 Solar charging | unit

Id: 15/23 Title: LPS Wiring Diagram


J4 Solar charging | unit

Id: 16/23 Title: LPS Wiring Diagram

J4 Solar charging | unit

Id: 17/23 Title: LPS Wiring Diagram


J4 Solar charging | unit

Id: 18/23 Title: LPS Wiring Diagram

J4 Solar charging | unit

Id: 19/23 Title: LPS Wiring Diagram


J4 Solar charging | unit

Id: 20/23 Title: LPS Wiring Diagram

J4 Solar charging | unit

Id: 21/23 Title: LPS Wiring Diagram

J4 Solar charging | unit

Id: 22/23 Title: LPS Wiring Diagram

J4 Solar charging | unit

Id: 23/23 Title: LPS Wiring Diagram

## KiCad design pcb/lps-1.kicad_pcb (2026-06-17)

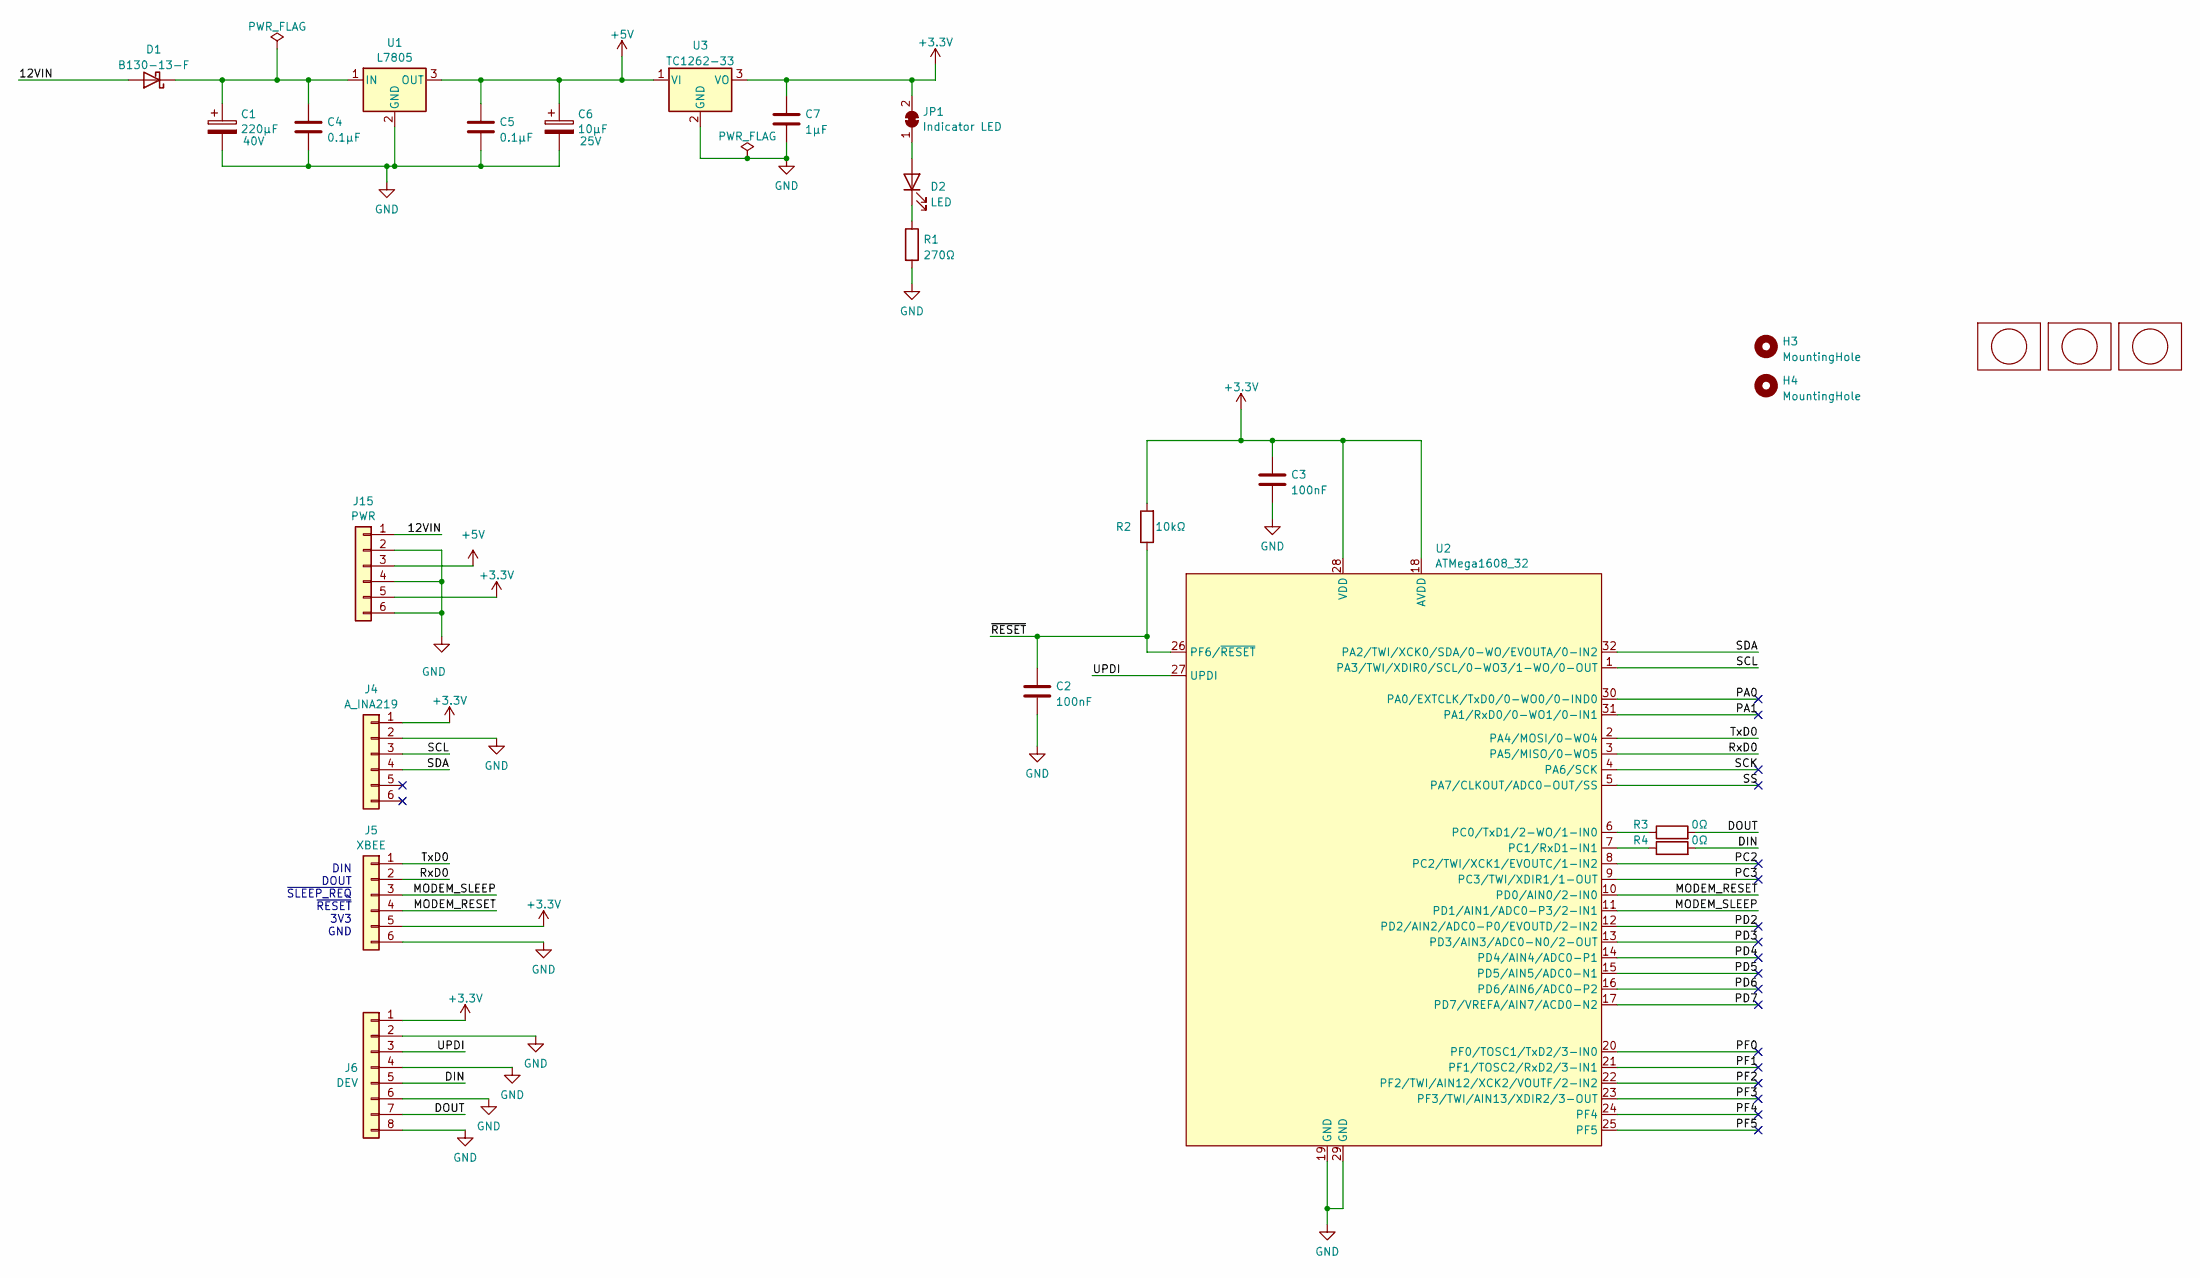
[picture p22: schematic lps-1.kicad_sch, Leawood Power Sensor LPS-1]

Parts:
C1: 220μF; CP_Radial_D10.0mm_P2.50mm; Voltage 40V
C2, C3: 100nF; C_0805_2012Metric
C4, C5: 0.1μF; C_0805_2012Metric_Pad1.18x1.45mm_HandSolder
C6: 10μF; CP_Radial_D5.0mm_P2.50mm; Voltage 25V
C7: 1μF; C_0805_2012Metric_Pad1.18x1.45mm_HandSolder
D1: B130-13-F; D_SMA; MPN B130-13-F
D2: LED; LED_0805_2012Metric
H3, H4: MountingHole; MountingHole_2.7mm_M2.5
J4: A_INA219; Adafruit-INA219_2xM2.5
J5: XBEE; PinHeader_2x03_P2.54mm_Vertical
J6: DEV; PinHeader_1x08_P2.54mm_Vertical
J15: PWR; PinHeader_1x06_P2.54mm_Vertical
JP1: Indicator LED; SolderJumper-2_P1.3mm_Bridged_RoundedPad1.0x1.5mm
Lg1, Lg2: logo; MyBasic_rounded_50_1
Lg3: logo; KiCad-Logo_5mm_SilkScreen
R1: 270Ω; R_0805_2012Metric
R2: 10kΩ; R_0805_2012Metric
R3, R4: 0Ω; R_0805_2012Metric
U1: L7805; TO-220-3_Vertical
U2: ATMega1608_32; TQFP-32_7x7mm_P0.8mm
U3: TC1262-33; SOT-223-3_TabPin2

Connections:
+3.3V: C3.1, C7.1, J4.1, J5.5, J6.1, J15.5, JP1.2 (B), R2.2, U2.18 (AVDD), U2.28 (VDD), U3.3 (VO)
+5V: C5.1, C6.1, J15.3, U1.3 (OUT), U3.1 (VI)
/12VIN: D1.2 (A), J15.1
/DIN: J6.5, R4.2
/DOUT: J6.7, R3.2
/MODEM_RESET: J5.4, U2.10 (PD0/AIN0/2-IN0)
/MODEM_SLEEP: J5.3, U2.11 (PD1/AIN1/ADC0-P3/2-IN1)
/PA0: U2.30 (PA0/EXTCLK/TxD0/0-WO0/0-IND0)
/PA1: U2.31 (PA1/RxD0/0-WO1/0-IN1)
/PC2: U2.8 (PC2/TWI/XCK1/EVOUTC/1-IN2)
/PC3: U2.9 (PC3/TWI/XDIR1/1-OUT)
/PD2: U2.12 (PD2/AIN2/ADC0-P0/EVOUTD/2-IN2)
/PD3: U2.13 (PD3/AIN3/ADC0-N0/2-OUT)
/PD4: U2.14 (PD4/AIN4/ADC0-P1)
/PD5: U2.15 (PD5/AIN5/ADC0-N1)
/PD6: U2.16 (PD6/AIN6/ADC0-P2)
/PD7: U2.17 (PD7/VREFA/AIN7/ACD0-N2)
/PF0: U2.20 (PF0/TOSC1/TxD2/3-IN0)
/PF1: U2.21 (PF1/TOSC2/RxD2/3-IN1)
/PF2: U2.22 (PF2/TWI/AIN12/XCK2/VOUTF/2-IN2)
/PF3: U2.23 (PF3/TWI/AIN13/XDIR2/3-OUT)
/PF4: U2.24 (PF4)
/PF5: U2.25 (PF5)
/RxD0: J5.2, U2.3 (PA5/MISO/0-WO5)
/SCK: U2.4 (PA6/SCK)
/SCL: J4.3, U2.1 (PA3/TWI/XDIR0/SCL/0-WO3/1-WO/0-OUT)
/SDA: J4.4, U2.32 (PA2/TWI/XCK0/SDA/0-WO/EVOUTA/0-IN2)
/SS: U2.5 (PA7/CLKOUT/ADC0-OUT/SS)
/TxD0: J5.1, U2.2 (PA4/MOSI/0-WO4)
/UPDI: J6.3, U2.27 (UPDI)
/~RESET: C2.1, R2.1, U2.26 (PF6/~RESET)
GND: C1.2, C2.2, C3.2, C4.2, C5.2, C6.2, C7.2, J4.2, J5.6, J6.2, J6.4, J6.6, J6.8, J15.2, J15.4, J15.6, R1.2, U1.2 (GND), U2.19 (GND), U2.29 (GND), U3.2 (GND)
unnamed: C1.1, C4.1, D1.1 (K), U1.1 (IN)
unnamed: D2.2 (A), JP1.1 (A)
unnamed: D2.1 (K), R1.1
unnamed: R3.1, U2.6 (PC0/TxD1/2-WO/1-IN0)
unnamed: R4.1, U2.7 (PC1/RxD1-IN1)

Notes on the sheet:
DIN DOUT ~{SLEEP_REQ} ~{RESET} 3V3 GND

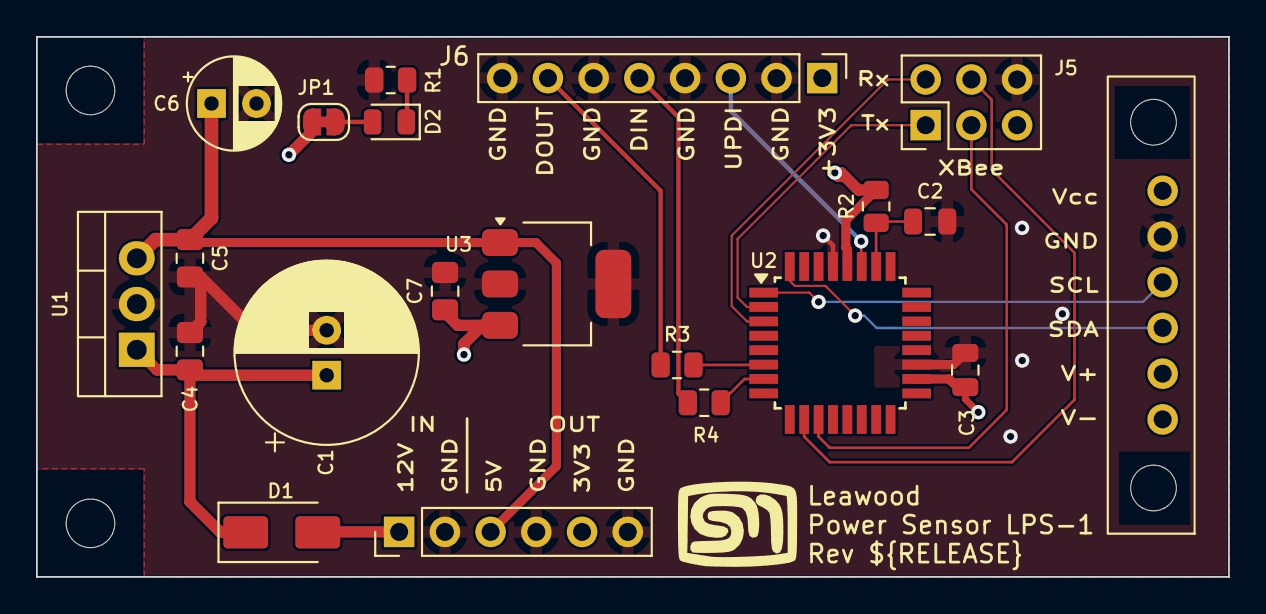
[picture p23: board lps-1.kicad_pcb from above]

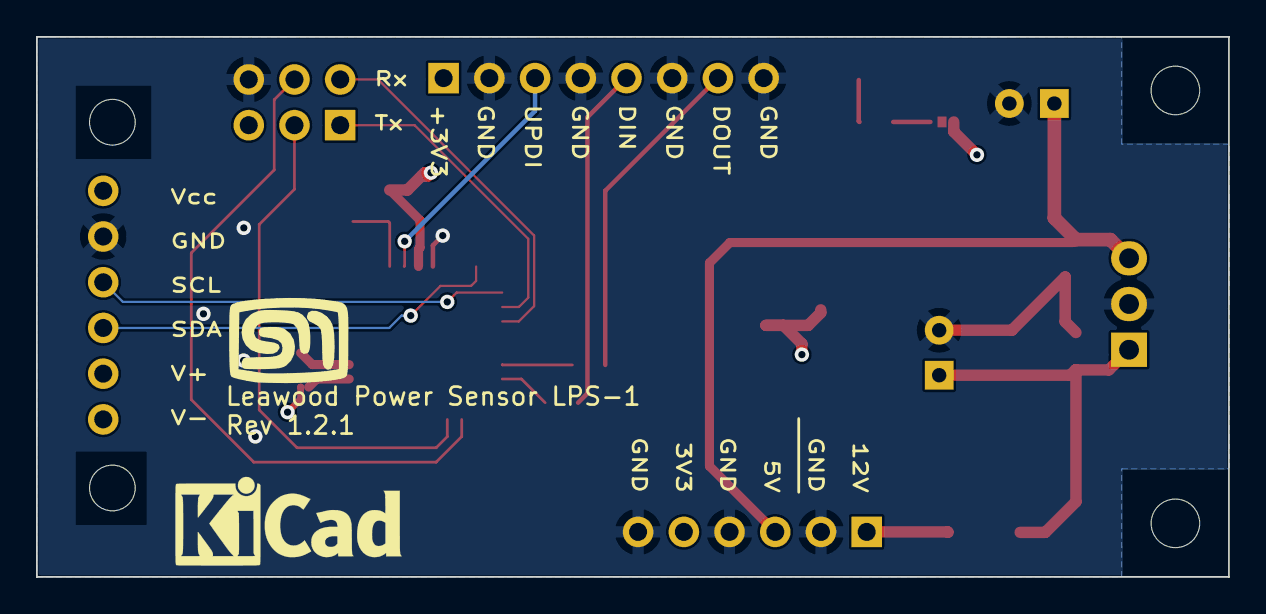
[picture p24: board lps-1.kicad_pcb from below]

Board: 4 copper layers, 66.2 x 30.0 mm, 26 parts (2 on the bottom side), 19 nets.

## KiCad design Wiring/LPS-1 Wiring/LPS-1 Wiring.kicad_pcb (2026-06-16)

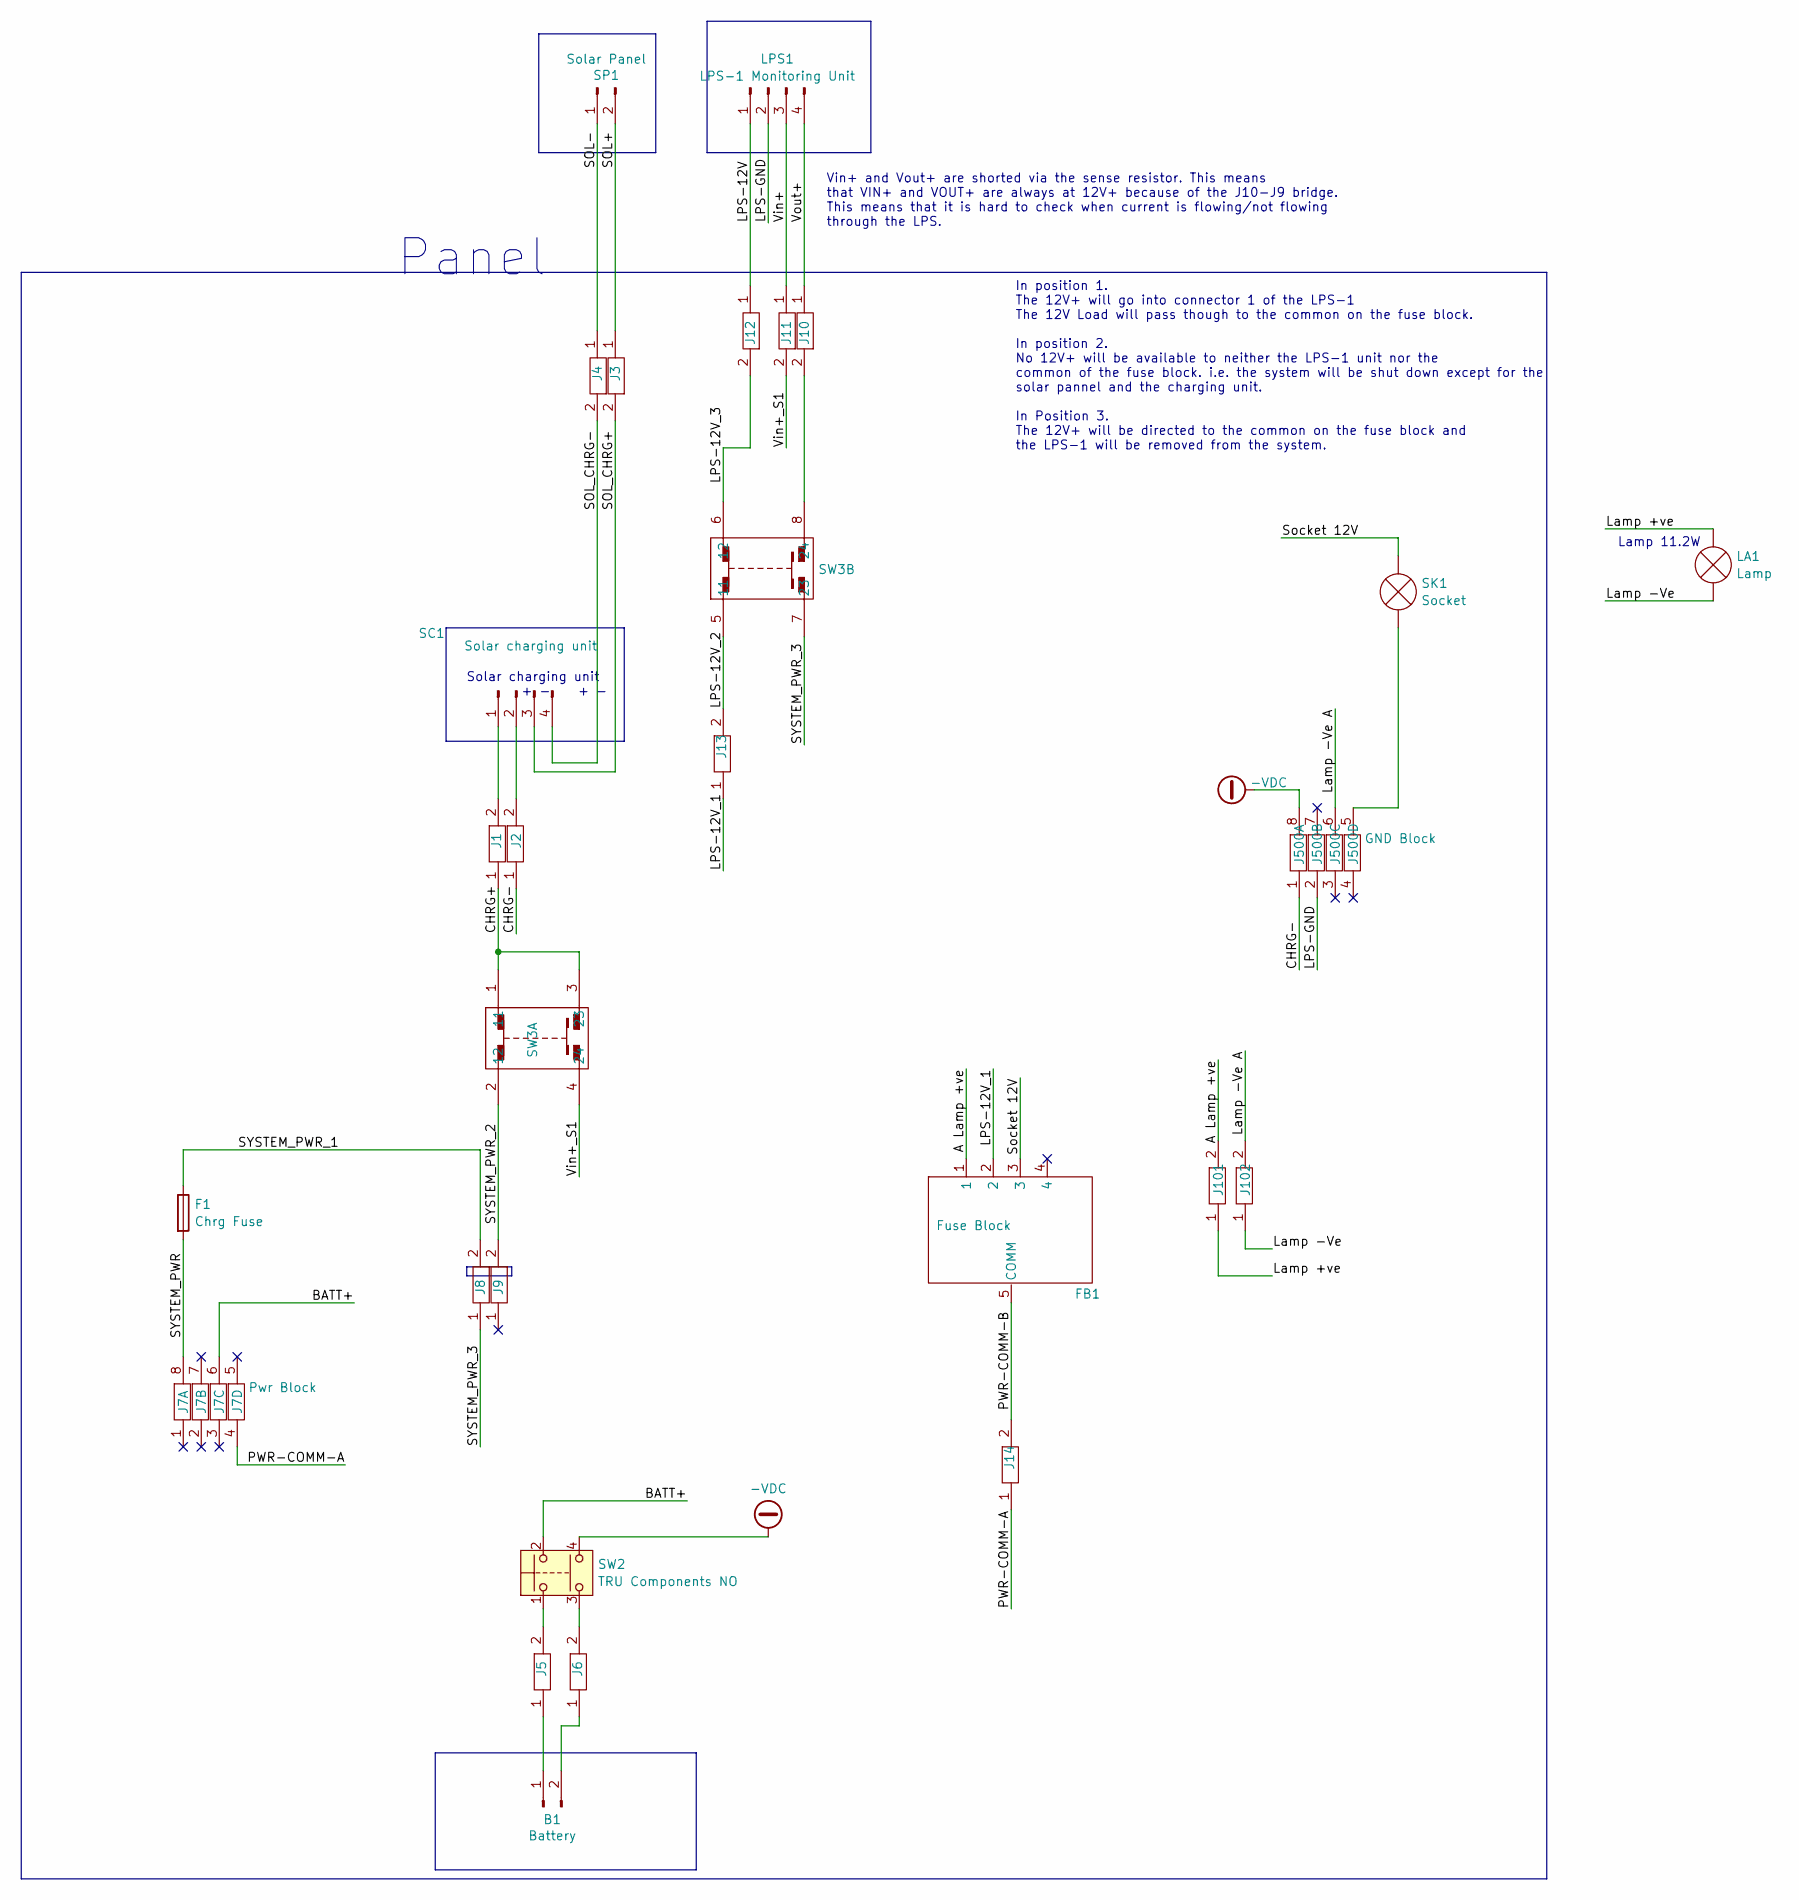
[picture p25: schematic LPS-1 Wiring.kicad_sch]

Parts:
B1: Battery; PinHeader_1x02_P2.54mm_Vertical
F1: Chrg Fuse; PinHeader_1x02_P2.54mm_Vertical
FB1: Fuse Block; FUSE_BLOCK_TRU_COMPONENTS-TC-9070396
J1, J2, J3, J4, J5, J6, J8, J9, J10, J11, J12, J13, J14, J101, J102: Block_Connector_01_b; Degson_01_PC2.5-01P-11-00AH-1_5.2
J7: Pwr Block; Degson_04_Bridged-PC2.5-01P-11-00AH-1_5.2
J500: GND Block; Degson_04_Bridged-PC2.5-01P-11-00AH-1_5.2
LA1: Lamp; PinHeader_1x02_P2.54mm_Vertical
LPS1: LPS-1 Monitoring Unit; LPS-1_EXT_PWR
SC1: Solar charging unit; H-TRONIC Solar-Lageregler
SK1: Socket; PinHeader_1x02_P2.54mm_Vertical
SP1: Solar Panel; PinHeader_1x02_P2.54mm_Vertical
SW2: TRU Components NO; TruComponents_SW_LAS0_1
SW3: TruComponents_SW_LAS0

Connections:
-VDC: J500.8, SW2.4 (24)
/A Lamp +ve: FB1.1, J101.2
/BATT+: J7.6, SW2.2 (12)
/CHRG+: J1.1, SW3.1 (11), SW3.3 (23)
/CHRG-: J2.1, J500.1
/LPS-12V: J12.1, LPS1.1
/LPS-12V_1: FB1.2, J13.1
/LPS-12V_2: J13.2, SW3.5 (11)
/LPS-12V_3: J12.2, SW3.6 (12)
/LPS-GND: J500.2, LPS1.2
/Lamp +ve: J101.1, LA1.2 (+)
/Lamp -Ve: J102.1, LA1.1 (-)
/Lamp -Ve A: J102.2, J500.6
/PWR-COMM-A: J7.4, J14.1
/PWR-COMM-B: FB1.5 (COMM), J14.2
/SOL+: J3.1, SP1.2
/SOL-: J4.1, SP1.1
/SOL_CHRG+: J3.2, SC1.3
/SOL_CHRG-: J4.2, SC1.4
/SYSTEM_PWR: F1.2, J7.8
/SYSTEM_PWR_1: F1.1, J8.2
/SYSTEM_PWR_2: J9.2, SW3.2 (12)
/SYSTEM_PWR_3: J8.1, SW3.7 (23)
/Socket 12V: FB1.3, SK1.2 (+)
/VIN+: J11.1, LPS1.3
/VIN-: J10.1, LPS1.4
/Vin+_S1: J11.2, SW3.4 (24)
unnamed: B1.1, J5.1
unnamed: B1.2, J6.1
unnamed: J1.2, SC1.1
unnamed: J2.2, SC1.2
unnamed: J500.5, SK1.1 (-)
unnamed: J5.2, SW2.1 (11)
unnamed: J6.2, SW2.3 (23)
unnamed: J10.2, SW3.8 (24)

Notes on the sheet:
Vin+ and Vout+ are shorted via the sense resistor. This means that VIN+ and VOUT+ are always at 12V+ because of the J10-J9 bridge. This means that it is hard to check when current is flowing/not flowing through the LPS.
In position 1. The 12V+ will go into connector 1 of the LPS-1 The 12V Load will pass though to the common on the fuse block. In position 2. No 12V+ will be available to neither the LPS-1 unit nor the common of the fuse block. i.e. the system will be shut down except for the solar pannel and the cha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
Solar charging unit + - + -
Lamp 11.2W
Panel

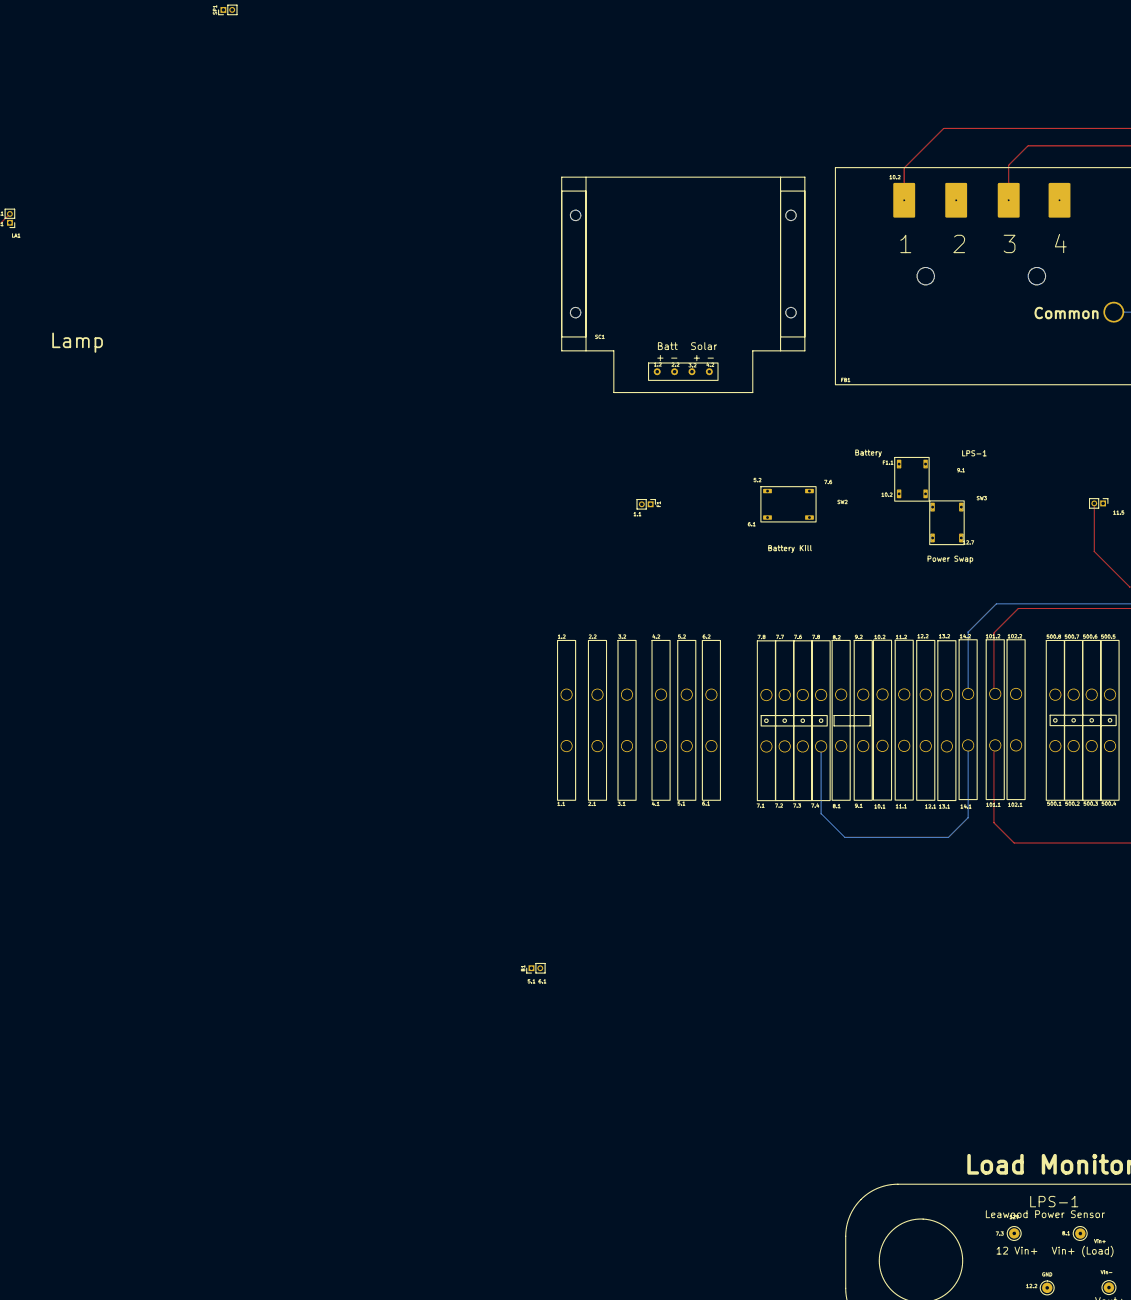
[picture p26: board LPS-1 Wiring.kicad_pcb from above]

Board: 32 copper layers, 27 parts (0 on the bottom side), 35 nets.

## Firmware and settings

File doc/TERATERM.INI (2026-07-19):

[BG]
; Use Eterm look-feel Background extension (on/off)
BGEnable=off

; Use AlphaBlend API (on/off)
BGUseAlphaBlendAPI=on

; Susie plugin path
BGSPIPath=plugin

; Fast window sizing/moving
BGFastSizeMove=on

; Flickerless window moving
BGFlickerlessMove=on

; If HideTitle=on and BGNoFrame=on, use window without frame
; you can resize window with Alt + Shift + LeftDrag
BGNoFrame=on

; wildcard => random select
BGThemeFile=theme\*.ini

; This option ignores the BGThemeFile in any case. When the option is on,
; the wallpaper image does not be mixed with theme file image.
BGIgnoreThemeFile=off


[Tera Term]
;	Tera Term version number
Version=4.106

;	Language (English/Japanese/Russian/Korean/UTF-8)
Language=English

; User interface language file that includes message strings.
; Tera Term uses built-in English message when the file or message is not found.
UILanguageFile=lang\Default.lng

; Connecting timeout value(per seconds). No action if the value is zero.
; Connecting socket could be canceled after the value timeout if the value is greater than zero.
; The default value is zero(depends on Windows TCP/IP stack implementation).
ConnectingTimeout=0

; pasting string by clicking mouse right button disabled
DisablePasteMouseRButton=off

; pasting string by clicking mouse middle button disabled
DisablePasteMouseMButton=on

; confirm pasting string by clicking mouse right button
ConfirmPasteMouseRButton=off

; confirm changing clipboard string by clicking mouse right button
ConfirmChangePaste=on
ConfirmChangePasteCR=on
PasteDialogSize=330,220
ConfirmChangePasteStringFile=

; Scroll out the current buffer when the clear screen does.
ScrollWindowClearScreen=on

; Reset scrollback on display activity
AutoScrollOnlyInBottomLine=on

; Starting the selection only by a left button.
SelectOnlyByLButton=on

; New connection by Alt-N Accelerator key
AcceleratorNewConnection=on

; Duplicate session by Alt-D Accelerator key disabled
DisableAcceleratorDuplicateSession=off

; Cygwin connection by Alt-G Accelerator key
AcceleratorCygwinConnection=on

; Send break by Alt-B Accelerator key disabled
DisableAcceleratorSendBreak=off

; New connection Menu disabled
DisableMenuNewConnection=off

; Duplicate session Menu disabled
DisableMenuDuplicateSession=off

; Send break Menu disabled
DisableMenuSendBreak=off

;	ANSI color definition (in the case FullColor=on)
;	* UseTextColor should be off, or the background and foreground color of
;	  VTColor are assigned to color-number 0 and 7 respectively, even if
;	  they are specified in ANSIColor.
;	* ANSIColor is a set of 4 values that are color-number(0--15),
;	  red-value(0--255), green-value(0--255) and blue-value(0--255).
ANSIColor=0,0,0,0, 1,255,0,0, 2,0,255,0, 3,255,255,0, 4,128,128,255, 5,255,0,255, 6,0,255,255, 7,255,255,255, 8,64,64,64, 9,192,0,0, 10,0,192,0, 11,192,192,0, 12,64,64,192, 13,192,0,192, 14,0,192,192, 15,192,192,192
; xterm
; ANSIColor=0,0,0,0, 1,255,0,0, 2,0,255,0, 3,255,255,0, 4,92,92,255, 5,255,0,255, 6,0,255,255, 7,255,255,255, 8,127,127,127, 9,205,0,0, 10,0,205,0, 11,205,205,0, 12,0,0,238, 13,205,0,205, 14,0,205,205, 15,229,229,229
; PuTTY
;ANSIColor=0,0,0,0, 1,255,85,85, 2,85,255,85, 3,255,255,85, 4,85,85,255, 5,255,85,255, 6,85,255,255, 7,255,255,255, 8,85,85,85, 9,187,0,0, 10,0,187,0, 11,187,187,0, 12,0,0,187, 13,187,0,187, 14,0,187,187, 15,187,187,187
; Tera Term Pro 2.3
;ANSIColor=0,0,0,0, 1,255,0,0, 2,0,255,0, 3,255,255,0, 4,0,0,255, 5,255,0,255, 6,0,255,255, 7,255,255,255, 8,128,128,128, 9,128,0,0, 10,0,128,0, 11,128,128,0, 12,0,0,128, 13,128,0,128, 14,0,128,128, 15,192,192,192
; Solarized (http://ethanschoonover.com/solarized)
;ANSIColor=0,7,54,66, 1,203,75,22, 2,88,110,117, 3,101,123,131, 4,131,148,150, 5,108,113,196, 6,147,161,161, 7,253,246,227, 8,0,43,54, 9,220,50,47, 10,133,153,0, 11,181,137,0, 12,38,139,210, 13,211,54,130, 14,42,161,152, 15,238,232,213
; Windows console new scheme (https://blogs.msdn.microsoft.com/commandline/2017/08/02/updating-the-windows-console-colors)
;ANSIColor=0,12,12,12, 1,231,72,86, 2,22,198,12, 3,249,241,165, 4,59,120,255, 5,180,0,158, 6,97,214,214, 7,242,242,242, 8,118,118,118, 9,197,15,31, 10,19,161,14, 11,193,156,0, 12,0,55,218, 13,136,23,152, 14,58,150,221, 15,204,204,204

;	Enable continued-line copy
EnableContinuedLineCopy=on

; Mouse cursor type (arrow/ibeam/cross/hand)
MouseCursor=ibeam

; Translucent window (0 - 255: transparency value)
AlphaBlend=255
AlphaBlendActive=255

; Cygwin install path
CygwinDirectory=

; Viewlog Editor path
ViewlogEditor=C:\WINDOWS\notepad.exe

; Locale for Unicode
;Locale=chs
Locale=english

; CodePage for Unicode
CodePage=1252

; Background color of text uses background color of screen (on/off)
UseNormalBGColor=on

;	Port type (serial/tcpip)
Port=serial

;	Window positions
VTPos=-2147483648,-2147483648
TEKPos=-2147483648,-2147483648

;	Terminal size
TerminalSize=159,61
;	Terminal size=window size (on/off)
TermIsWin=on
;	Auto window resizing option (on/off)
AutoWinResize=off
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

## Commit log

2024-01-02 Started the KiCad project
    [lps-1.kicad_pcb, lps-1.kicad_sch]
2024-01-28 First layout
    [lps-1.kicad_pcb, lps-1.kicad_sch]
2024-03-12 Refactored the connectors for the LPS-X-1
    [lps-1.kicad_pcb, lps-1.kicad_sch]
2024-03-13 Reduces the board footprint and introduces copper fills on F and B
    [lps-1.kicad_pcb, lps-1.kicad_sch]
2024-03-22 Rework to include a 5V LDO
    [Wakefield-E274-Body.step, Wakefield-E274.FCStd, Wakefield-E274.step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]
2024-03-26 Reworked the connectors
    [lps-1.kicad_pcb, lps-1.kicad_sch]
2024-04-16 Revision 1.0
    [lps-1.kicad_pcb, lps-1.kicad_sch]
2024-04-25 Fixes the drill holes for the INA219
    [lps-1-B_Cu.gbr, lps-1-B_Mask.gbr, lps-1-B_Paste.gbr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]
2024-04-26 Revision 1.01 Gerbers
    [lps-1-B_Cu.gbr, lps-1-B_Mask.gbr, lps-1-B_Paste.gbr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]
2024-05-12 Correction to the TWI0 pin selection
    [lps-1-B_Cu.gbr, lps-1-B_Mask.gbr, lps-1-B_Paste.gbr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]
2024-05-15 Created keep out zones around the mounting holes
    [lps-1.kicad_pcb, lps-1.kicad_sch]
2025-03-08 Update and sync
    [3D File NE8FDIS-TOP.stp, ConnectorPanel.FCStd, Drawing NE8FDIS-TOP.dxf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]
2025-12-09 Adds wiring diagram
    [LPS-1 Wiring.kicad_pcb, LPS-1 Wiring.kicad_sch]
2025-12-09 Chagnes to the panel layout
    [LPS-1 Wiring.kicad_pcb]
2026-05-22 Moved the design to KiCad 10
    [LPS-1 Wiring.kicad_pcb, LPS-1 Wiring.kicad_sch]
2026-05-23 Update to the connection block symols and footprints
    [LPS-1 Wiring.kicad_pcb, LPS-1 Wiring.kicad_sch]
2026-06-04 Adds release script
    [lps-1.kicad_pcb, lps-1.kicad_sch]
2026-06-04 Updated the wiring diagram
    [LPS-1 Wiring.kicad_pcb, LPS-1 Wiring.kicad_sch]
2026-06-04 Refactored the reference numbering
    [LPS-1 Wiring.kicad_pcb, LPS-1 Wiring.kicad_sch]
2026-06-08 Refactored the nomenclature for non-connector components
    [LPS-1 Wiring.kicad_pcb, LPS-1 Wiring.kicad_sch]
2026-06-12 Updates to the wriging layout
    [LPS-1 Wiring.kicad_pcb, LPS-1 Wiring.kicad_sch]
2026-06-13 Reconfigured the LPS-1 wiring
    [LPS-1 Wiring.kicad_pcb, LPS-1 Wiring.kicad_sch]
2026-06-16 Panel wiring update
    [LPS-1 Wiring.kicad_pcb, LPS-1 Wiring.kicad_sch]
2026-06-17 Local update
    [Connection.fzz, lps-1.kicad_pcb, lps-1.kicad_sch]
2026-06-17 Fz update
    [Connection.fzz]
